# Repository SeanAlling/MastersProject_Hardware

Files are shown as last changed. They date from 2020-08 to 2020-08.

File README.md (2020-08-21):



# Overview 

Contains within this repository are the hardware files used for my masters project. One will find two sub directories

1. PrimaryPCB
1. TestBed

## Primary  PCB

This folder contains main PCB developed for the masters project. 

## Testbed 

This folder contain a PCB that can be used to simplify running experiments with the primary PCB.

# Special Thanks

<table><tr>
<td>  </td>
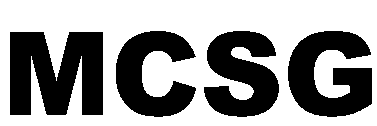
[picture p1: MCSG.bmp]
<td>  </td>
</tr></table>

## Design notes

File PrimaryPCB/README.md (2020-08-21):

# Overview

The project enclosed is the final version designed, developed, assembled, and tested for my Masters project at UC Davis. 

# Dependencies

This project was developed using EagleCAD 9.4.2. Different versions of eagle are not guaranteed to work.

__NOTE__: Libraries are not provided. Only the schematic and PCB project files are included.

# Project Structure

## BOM (Bill Of Material)

The BOM folder contains two different BOMs. First is a standard bill of material and contains an itemized list of the parts used in the project. 

A second BOM call iBOM (interactive BOM) is included that can be used to help find part placement during assembly.

## Documentation

Documentation folder contains a single PDF. The PDF contains all schematics, along with renderings of the top and bottom of the PCB, and images of each layer. 

## Gerbers

Contains a zip file that can be used for ordering the PCB from a manufacturer.

## Images

Raw images that are used in Documentation PDF.

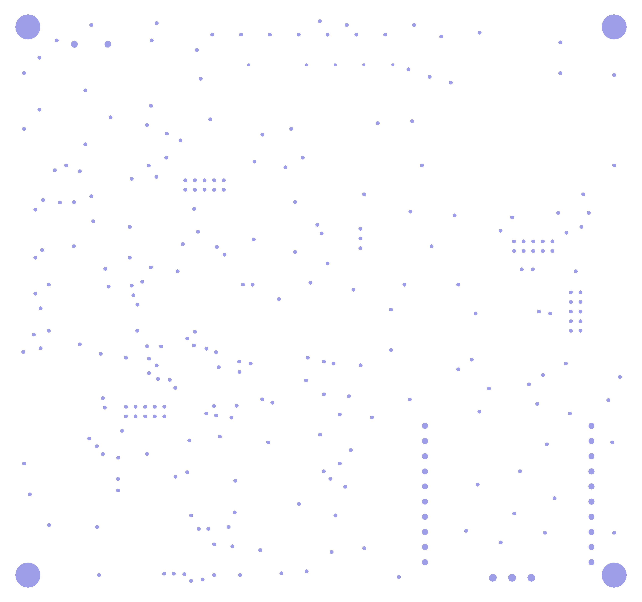
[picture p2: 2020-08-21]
PrimaryPCB/Images/output.png

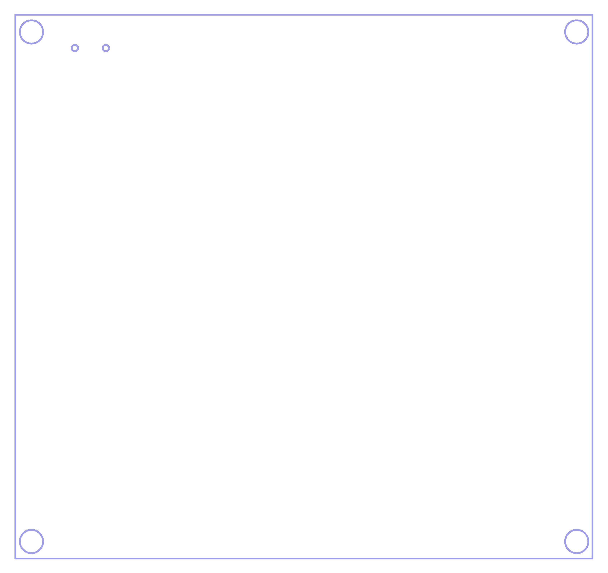
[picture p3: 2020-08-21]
PrimaryPCB/Images/bottompaste.png

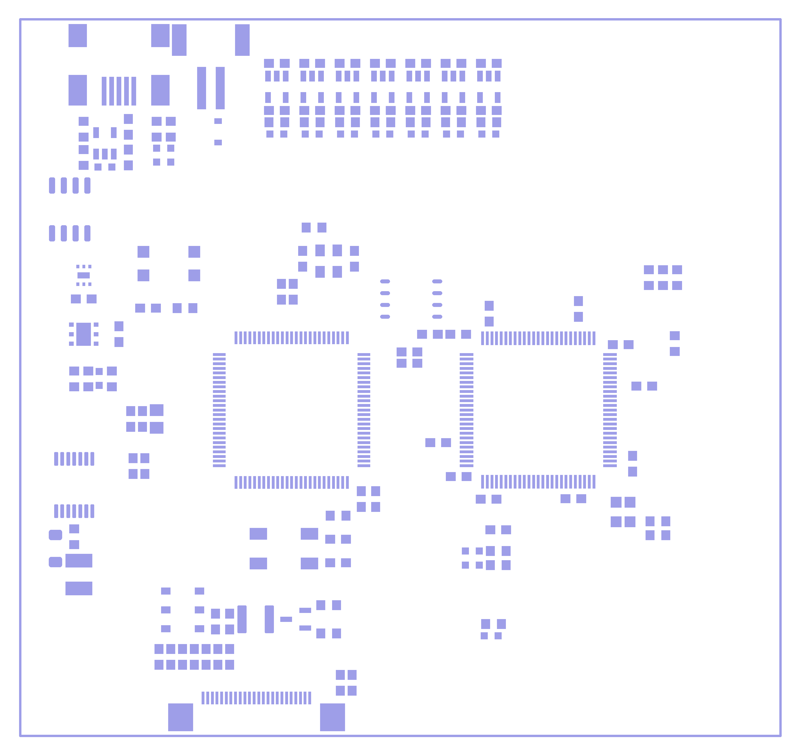
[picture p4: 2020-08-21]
PrimaryPCB/Images/topstencil.png

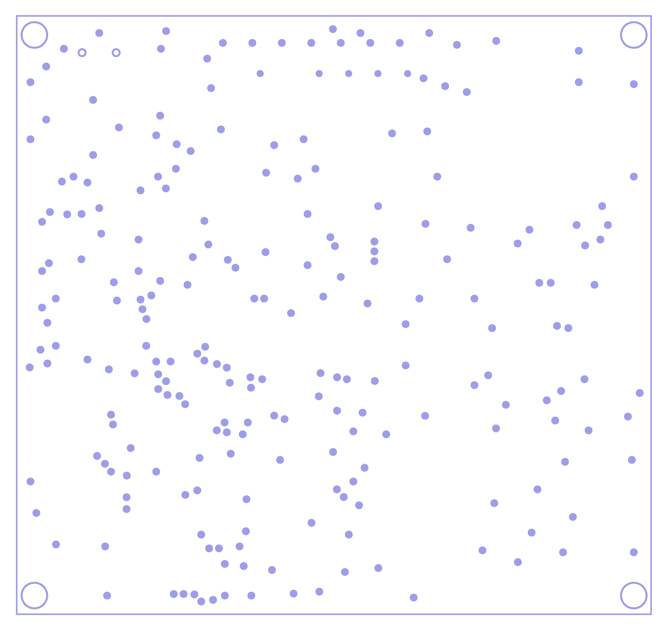
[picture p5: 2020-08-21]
PrimaryPCB/Images/drills.png

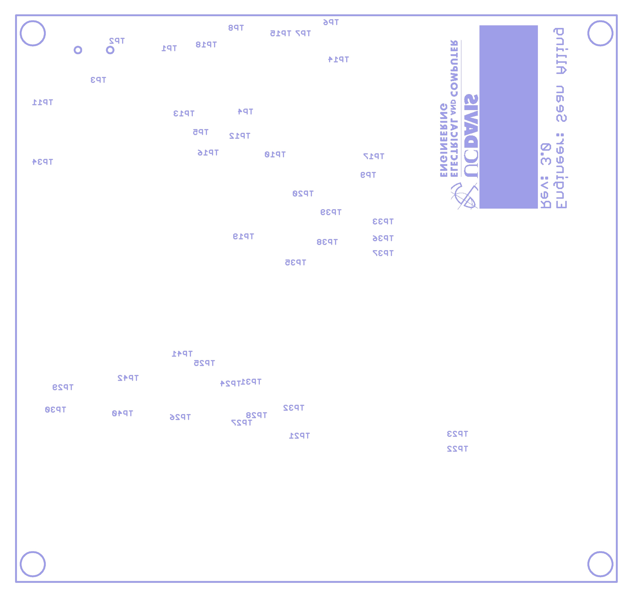
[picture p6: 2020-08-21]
PrimaryPCB/Images/bottomsilkscreen.png

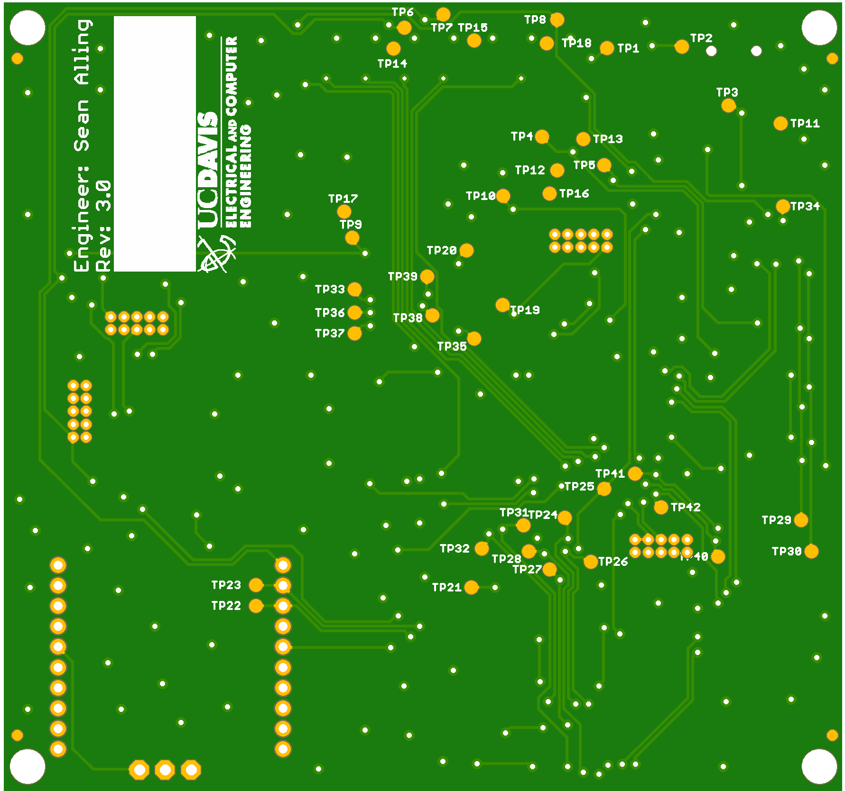
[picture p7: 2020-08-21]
PrimaryPCB/Images/PCB_Bottom.png

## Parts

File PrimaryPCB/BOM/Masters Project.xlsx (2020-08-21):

Qty | "Value" | "Package" | DIGIKEY
26 | "1uF" | "C0603" | 1276-1860-1-ND
6 | "4.7uF" | "C0603" | 1276-1907-1-ND
11 | "0.1uF" | "C0603" | 399-1100-1-ND
6 | "100nF" | "C0603" | 399-1100-1-ND
1 | "1nF" | "C0603" | 399-7833-1-ND
4 | "22pF" | "C0603" | 399-7874-1-ND
1 | "4uF" | "C0603" | 1276-1907-1-ND
1 | "47uF" | "C0603" | 490-13247-1-ND
1 | "11mF" | "C1210K" | 728-1127-1-ND
3 | "SCHOTTKY" | "SOD3716X128" | MBR0530T1GOSCT-ND
1 | "250mA/100V" | "SOD-323" | 1727-6169-1-ND
13 | "GREEN" | "CHIPLED_0603" | 732-4971-1-ND
1 | "RED" | "CHIPLED_0603" | 732-4978-1-ND
2 | "GREEN" | "SML0805" | 732-4983-1-ND
4 | "STAND-OFF" | "STAND-OFF"
1 | " " | "JST-2-SMD"
4 | "2X5_HEADER1.27MM" | "CORTEX_DEBUG_10PIN" | 3220-10-0100-00
1 | "1X3_HEADER" | "1X3_FEMALE_HEADER_THROUGH_HOLE" | S1012EC-40-ND
2 | " " | "XBEE-1" | ED11245-ND
1 | "4.7uH" | "L-USL0805" | LQM21PN4R7NGRD
1 | "100uH" | "LPS3015" | LPS3015-104MRC
1 | "CPFBZ-A2C4-32.768KD6" | "CPFBZ-A2C4-32.768KD6" | CPFBZ-A2C4-32.768KD6
1 | "ABM8-48.000MHZ-B2-T" | "CRYSTAL_4-SMD" | ABM8-48.000MHZ-B2-T
1 | "MOSFET-NCH" | "SOT95P237X112-3" | IRLML6346TRPBF
1 | "ABS07-LR" | "2-SMD" | ABS07-LR-32.768KHZ-6-T
1 | "0.47" | "R0603" | UCR03EVPFLR470
1 | "100k" | "R0603" | CR0603-JW-104ELF
9 | "1k" | "R0603" | 311-1.0KGRCT-ND
10 | "330" | "R0603" | CR0603-JW-331ELF
2 | "2k" | "R0603" | RC0603FR-072KL
2 | "10k" | "R0603" | RC0603JR-0710KL
1 | "91k" | "R0603" | RC0603FR-0791KL
3 | "51k" | "R0603" | RMCF0603JT5K10
1 | "TACTILE-SWITCH-SMT" | "7914G" | 7914G-1-000E
1 | "LCMXO2-640HC-4TG100C-NEW" | "QFP50P1600X1600X160-100N" | LCMXO2-640HC-4TG100C
1 | "MCP73831" | "SOT23-5L" | MCP73831T-2DCI/OT
6 | "STLQ015M33R" | "SOT23-5L" | STLQ015M33R
1 | "STLQ015M12R" | "SOT23-5L" | STLQ015M12R
1 | "HDC1080" | "WSON-6" | HDC1080DMBR
1 | "OPT3001" | "USON-6" | OPT3001DNPR
1 | "MSP432P401R" | "LQFP100" | MSP432P401RIPZR
1 | "AT25SL128A" | "SON127P600X500X60-8N" | AT25SL128A-MHE-T
1 | "PCF8523" | "TSSOP14" | PCF8523TS/1,118
1 | "FM24CL16B" | "FM24CL16B" | FM24CL16B-G
1 | "4.2-E-INK-DISPLAY" | "FPC-24PIN-0.5MM" | 524352471
1 | "MINI-USB-32005-201" | "32005-201" | UJ2-MABH-1-SMT-TR

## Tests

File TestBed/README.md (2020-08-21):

# Overview

The testbed project was designed to make reading test points simpler. Pogo pins are laid  out such that they align with a test pad on the primary PCB. The testbed also uses right angle header pins located to the sides of the PCB to allow probing signals. 

# Test Points

| TestPoint | Description |
| --- |:---:|
| 1 | +BAT|
| 2 | GND|
| 3 | VCC_USB|
| 4 | VCC_HDC1080|
| 5 | VCC_OPT3001|
| 6 | VCC_FPGA|
| 7 | VCC_XBEE|
| 8 | VCC_MEMORY|
| 9 | VCC_DISPLAY|
| 10 | VCC_MCU|
| 11 | GND|
| 12 | GND|
| 13 | GND|
| 14 | GND|
| 15 | GND|
| 16 | GND|
| 17 | GND|
| 18 | GND|
| 19 | <span style="text-decoration:overline">RST</span>|
| 20 | N$139|
| 21 | N$131|
| 22 | UART_TX_XBEE|
| 23 | UART_RX_XBEE|
| 24 | SPI_CLK|
| 25 | CHARGE_STATUS|
| 26 | SPI_MOSI|
| 27 | DISPLAY_D/<span style="text-decoration:overline">C</span>|
| 28 | SPI_CS_DISPLAY|
| 29 | MCU_SCL|
| 30 | MCU_SDA|
| 31 | EINK_<span style="text-decoration:overline">RST</span>|
| 32 | EINK_BUSY|
| 33 | <span style="text-decoration:overline">FLASH_WP</span>|
| 34 | FRAM_WP|
| 35 | <span style="text-decoration:overline">FLASH_HOLD</span>|
| 36 | MCU_SPI_MISO|
| 37 | MCU_SPI_CS|
| 38 | MCU_SPI_CLK|
| 39 | SPI_MOSI|
| 40 | <span style="text-decoration:overline">RTC_IN1</span>|
| 41 | RTC_CLKOUT|
| 42 | <span style="text-decoration:overline">RTC_INT2</span>|

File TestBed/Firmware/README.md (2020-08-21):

# Dependencies
This project was created using STM32CubeMX Version 5.2.0. Only Version 5.2.0 of STM32CubeMX is guaranteed to work.

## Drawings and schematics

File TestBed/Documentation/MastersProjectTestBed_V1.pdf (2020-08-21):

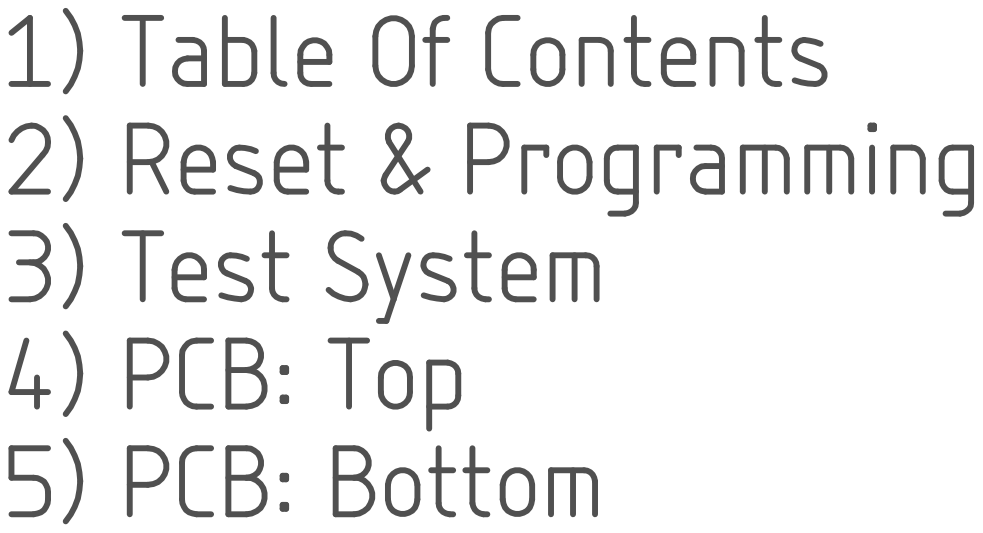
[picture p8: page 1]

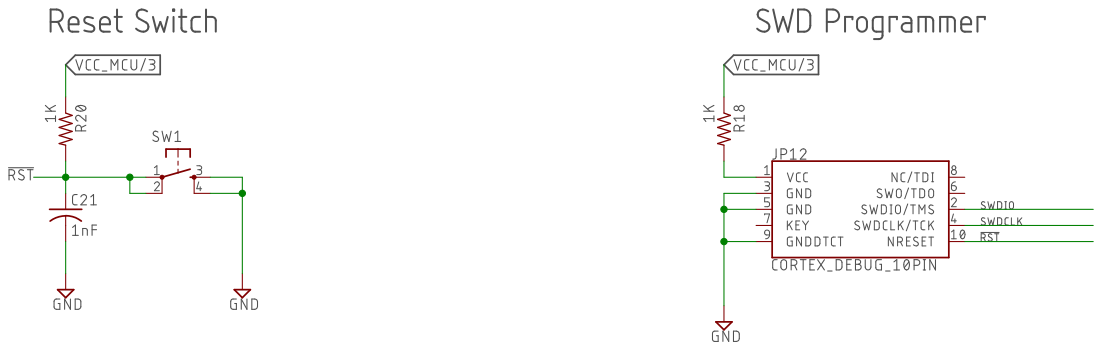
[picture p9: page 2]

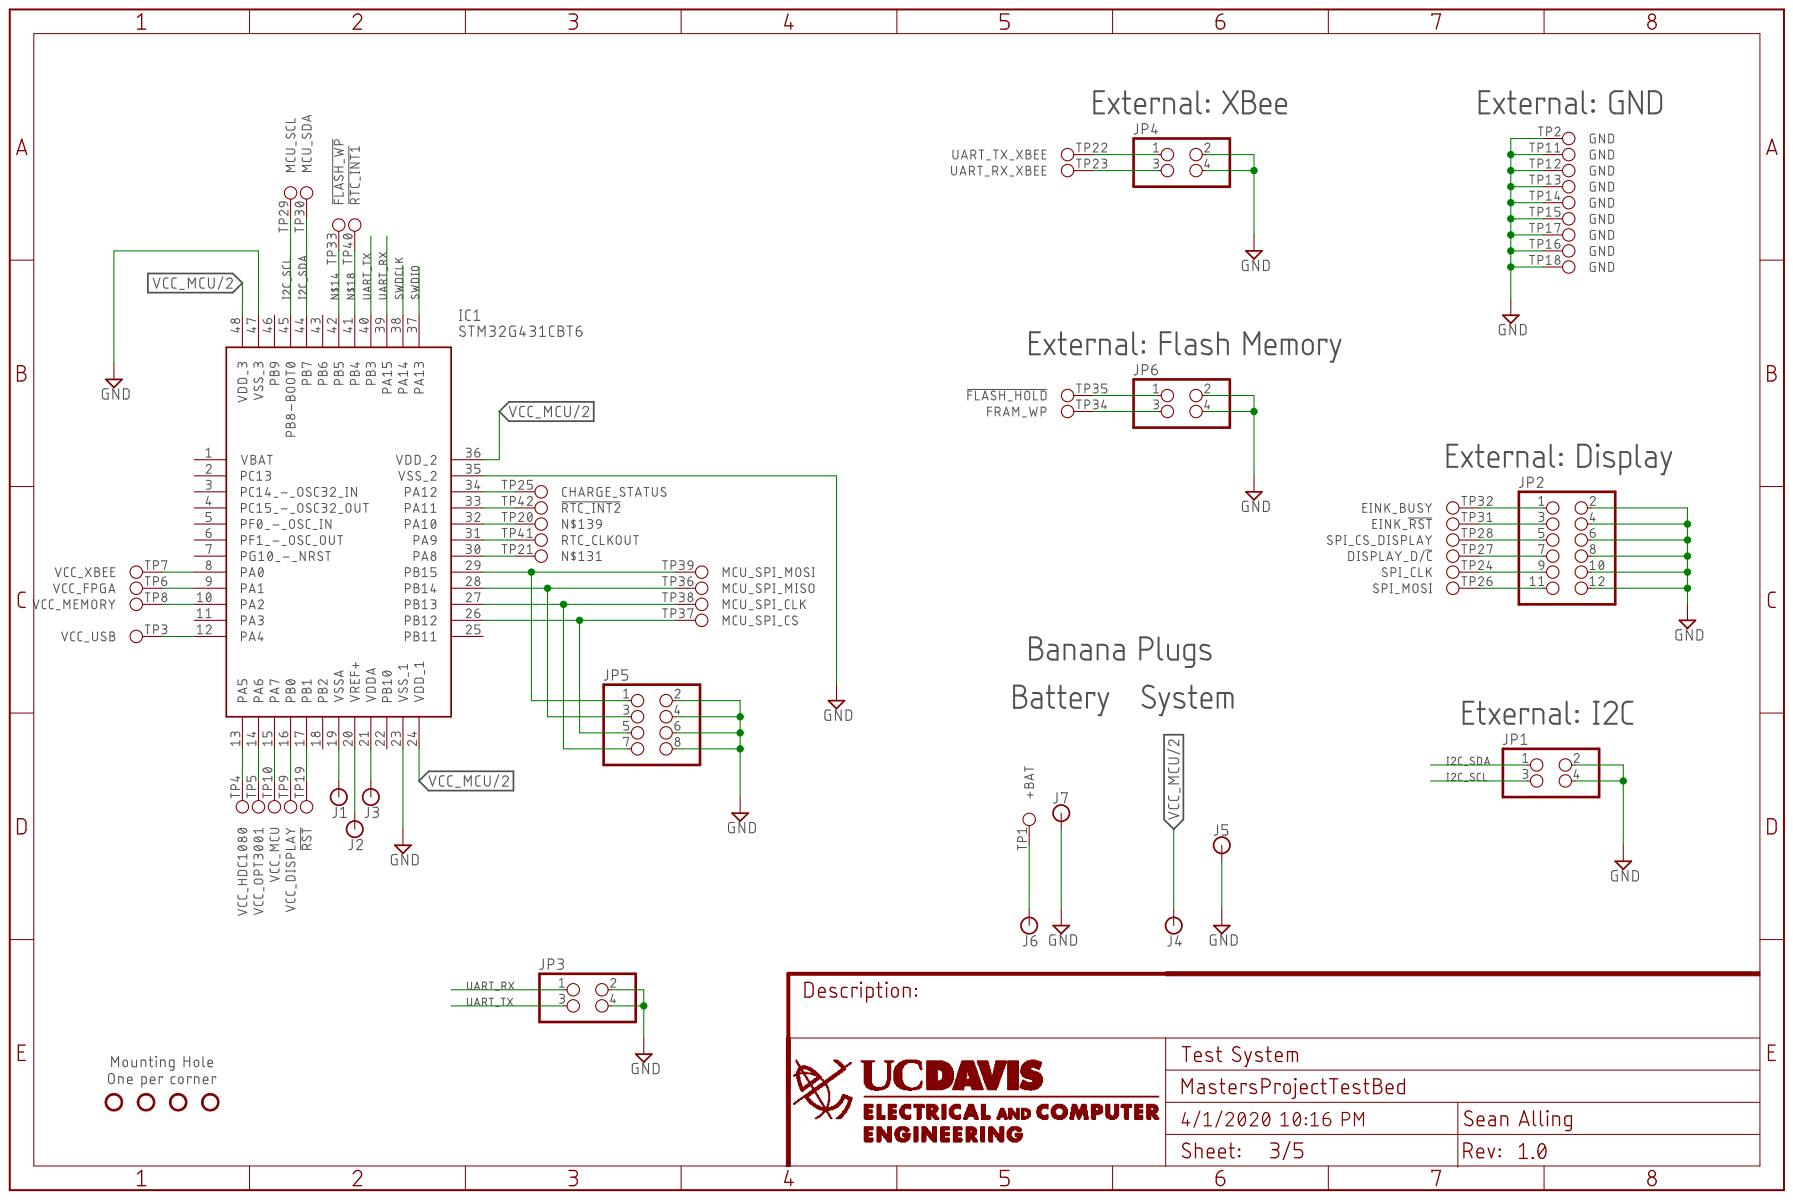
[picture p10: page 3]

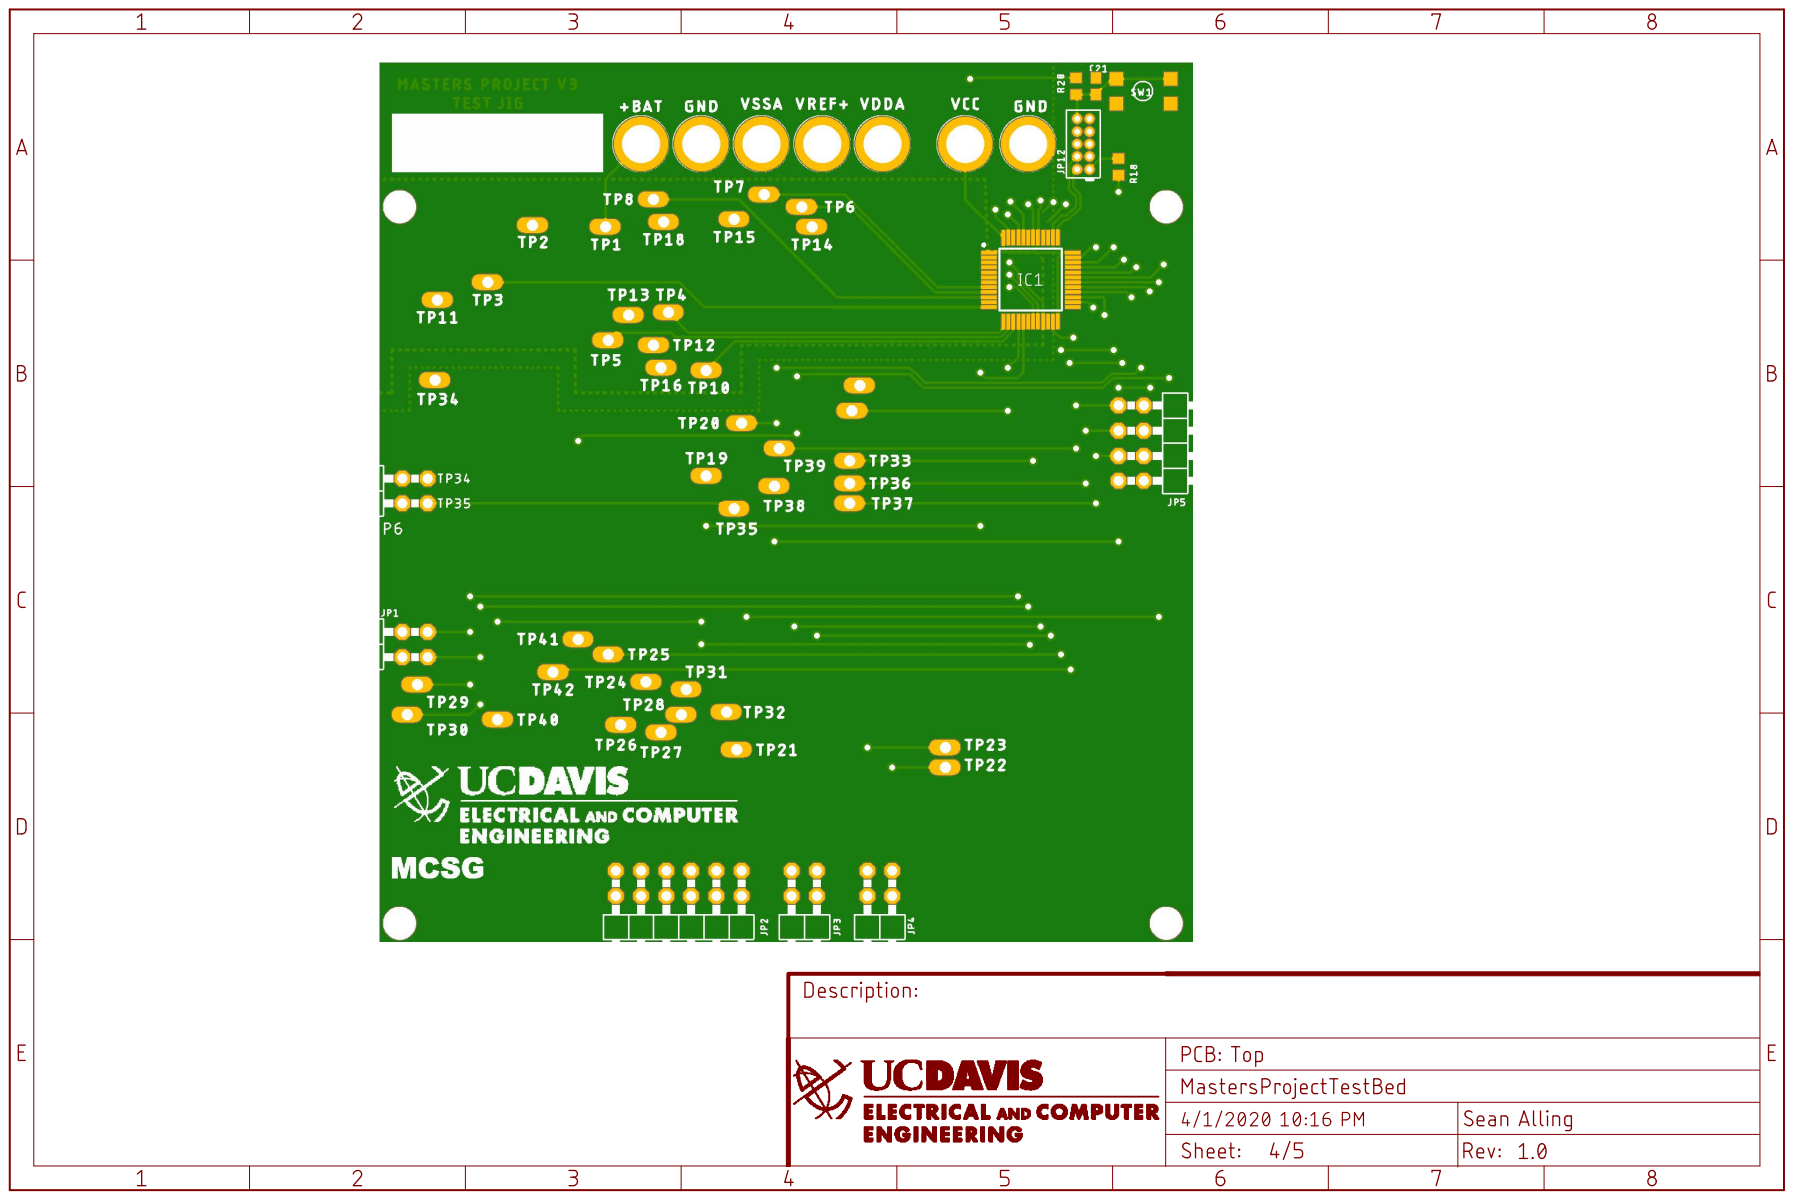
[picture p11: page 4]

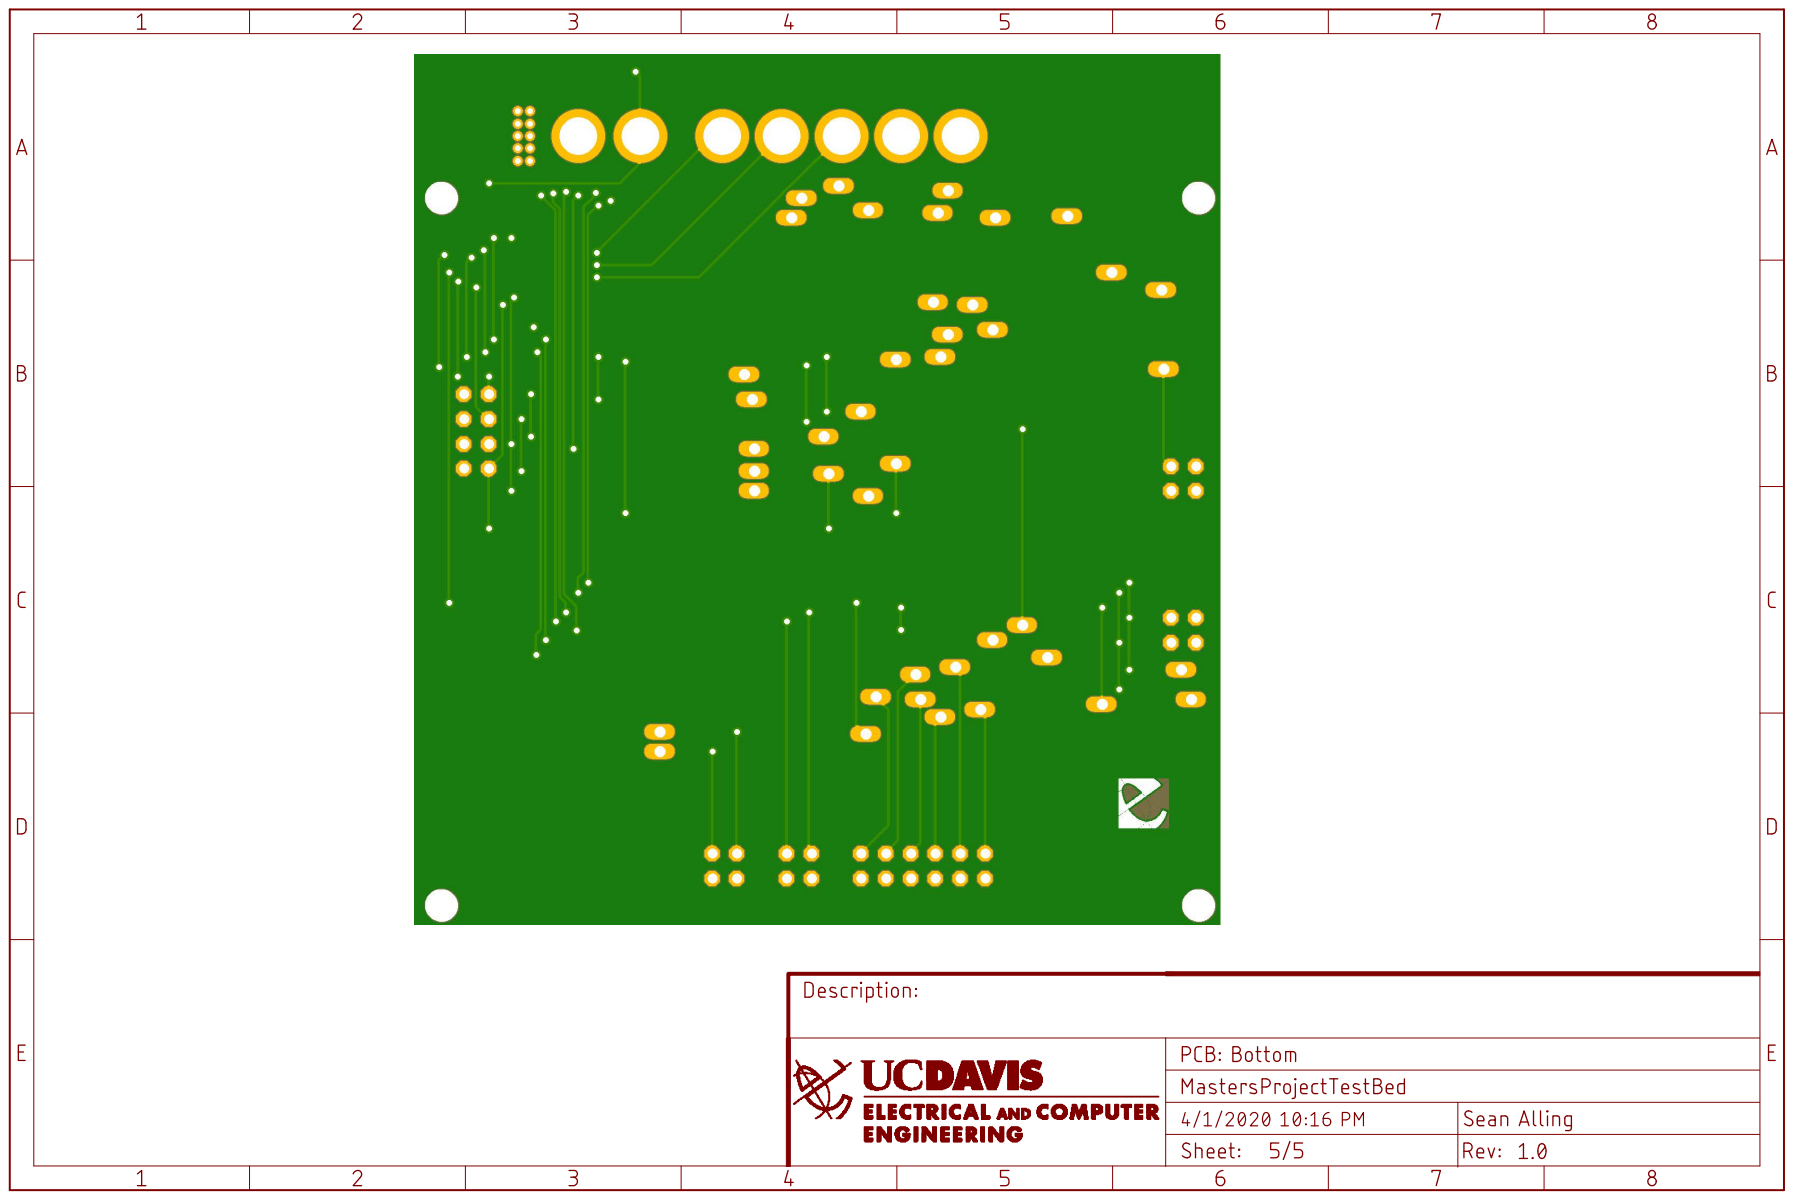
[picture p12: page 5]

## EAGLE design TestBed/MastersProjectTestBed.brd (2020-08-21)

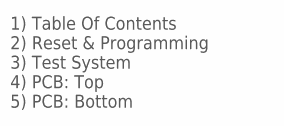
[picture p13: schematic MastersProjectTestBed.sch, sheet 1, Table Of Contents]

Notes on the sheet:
1) Table Of Contents 2) Reset & Programming 3) Test System 4) PCB: Top 5) PCB: Bottom

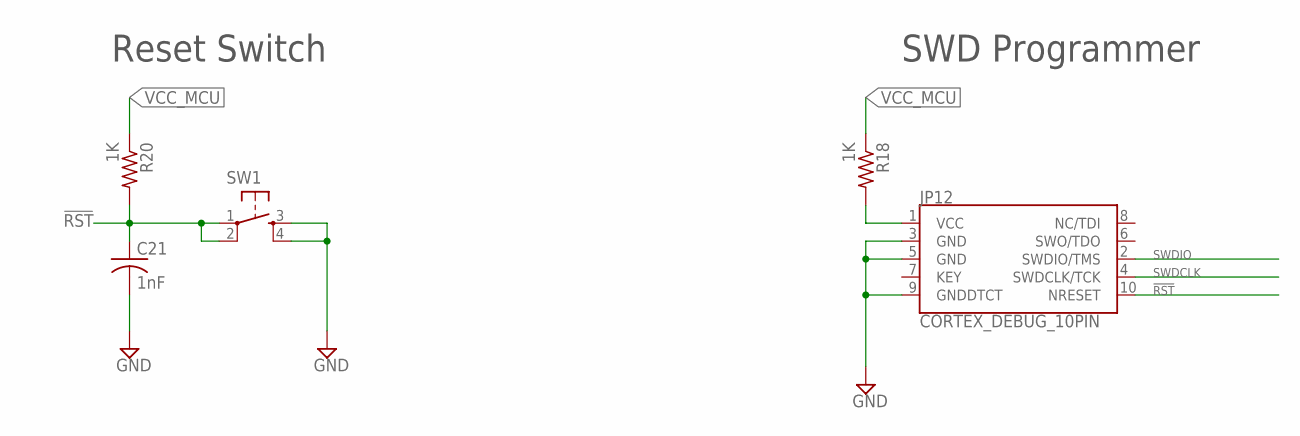
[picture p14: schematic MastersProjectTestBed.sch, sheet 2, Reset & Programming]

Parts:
C21: 1nF; C0603; PARTNO 08053F102K4T2A
JP12: CORTEX_DEBUG_10PIN; PARTNO 3220-10-0100-00
R18, R20: 1K; R0603; PARTNO RC0805JR-071KL
SW1: TACTILE-SWITCH-SMT; 7914G; PARTNO 7914G-1-000E

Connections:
!RST: C21.1, JP12.10 (NRESET), R20.2, SW1.1, SW1.2
GND: C21.2, JP12.3 (GND), JP12.5 (GND), JP12.9 (GNDDTCT), SW1.3, SW1.4; also elsewhere on the board
unnamed: JP12.1 (VCC), R18.2
SWDCLK: JP12.4 (SWDCLK/TCK); also elsewhere on the board
SWDIO: JP12.2 (SWDIO/TMS); also elsewhere on the board
VCC_MCU: R18.1, R20.1; also elsewhere on the board

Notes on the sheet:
SWD Programmer
Reset Switch

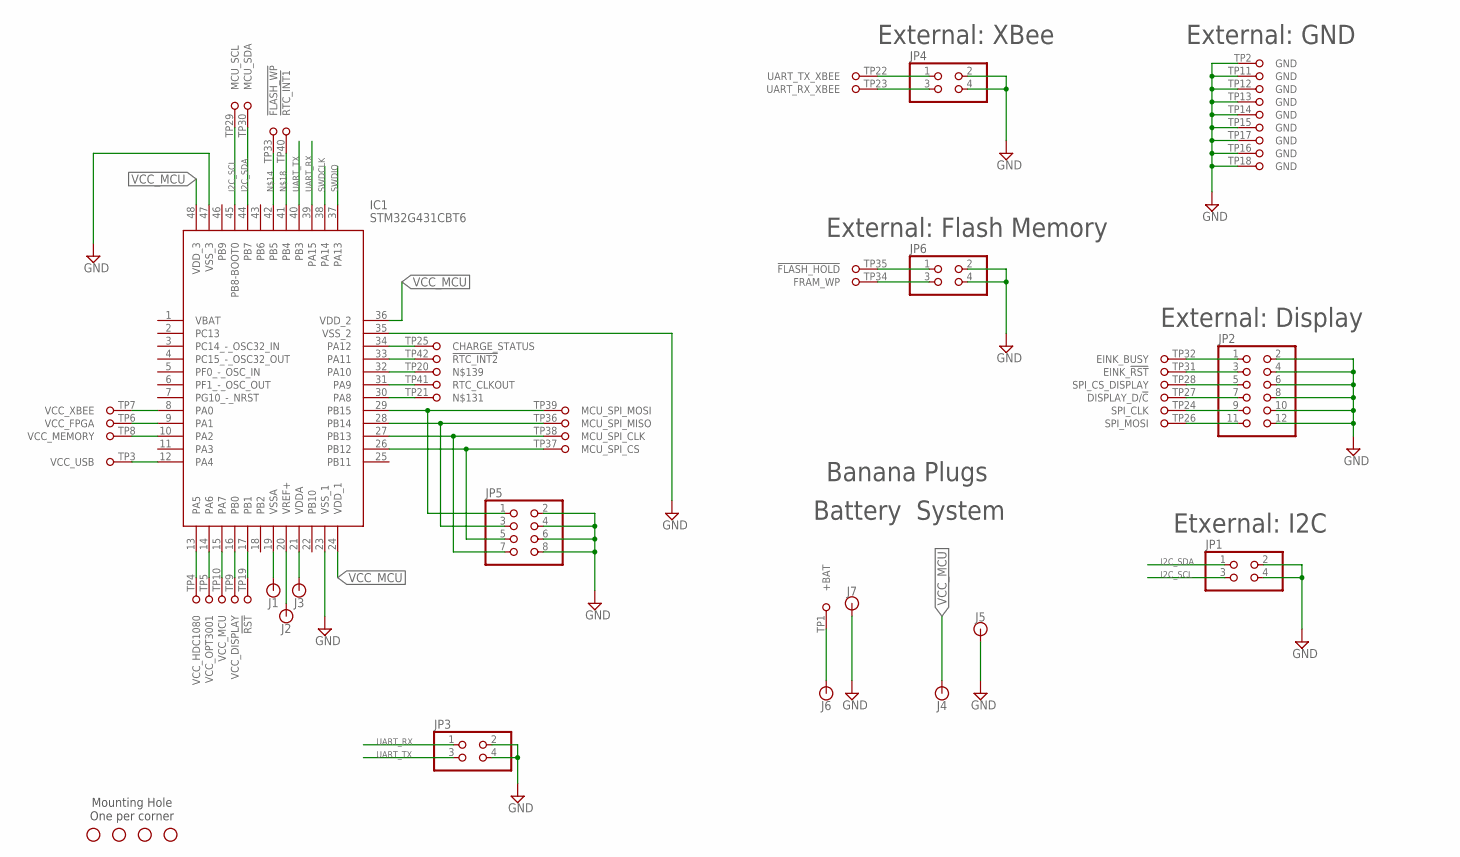
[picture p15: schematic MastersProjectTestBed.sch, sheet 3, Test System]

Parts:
H1, H2, H3, H4: STAND-OFF
IC1: STM32G431CBT6; QFP50P900X900X160-48N
J1, J2, J3, J4, J5, J6, J7: BANANA_CONN
JP1, JP3, JP4, JP6: PINHD-2X2/90; 2X02/90
JP2: PINHD-2X6/90; 2X06/90
JP5: PINHD-2X4/90; 2X04/90
TP1: PCB-POGO

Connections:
GND: IC1.23 (VSS_1), IC1.35 (VSS_2), IC1.47 (VSS_3), J5.P$1, J7.P$1, JP1.2, JP1.4, JP2.2, JP2.4, JP2.6, JP2.8, JP2.10, JP2.12, JP3.2, JP3.4, JP4.2, JP4.4, JP5.2, JP5.4, JP5.6, JP5.8, JP6.2, JP6.4, TP1.TP2 (GND), TP1.TP11 (GND), TP1.TP12 (GND), TP1.TP13 (GND), TP1.TP14 (GND), TP1.TP15 (GND), TP1.TP16 (GND), TP1.TP17 (GND), TP1.TP18 (GND); also elsewhere on the board
I2C_SCL: IC1.45 (PB8-BOOT0), JP1.3, TP1.TP29 (MCU_SCL)
I2C_SDA: IC1.44 (PB7), JP1.1, TP1.TP30 (MCU_SDA)
unnamed: IC1.9 (PA1), TP1.TP6 (VCC_FPGA)
unnamed: IC1.8 (PA0), TP1.TP7 (VCC_XBEE)
unnamed: IC1.10 (PA2), TP1.TP8 (VCC_MEMORY)
unnamed: J6.P$1, TP1.TP1 (+BAT)
unnamed: IC1.12 (PA4), TP1.TP3 (VCC_USB)
unnamed: IC1.33 (PA11), TP1.TP42 (!RTC_INT2)
unnamed: IC1.34 (PA12), TP1.TP25 (CHARGE_STATUS)
unnamed: IC1.13 (PA5), TP1.TP4 (VCC_HDC1080)
unnamed: IC1.14 (PA6), TP1.TP5 (VCC_OPT3001)
unnamed: IC1.15 (PA7), TP1.TP10 (VCC_MCU)
unnamed: IC1.17 (PB1), TP1.TP19 (!RST)
unnamed: IC1.30 (PA8), TP1.TP21
unnamed: IC1.42 (PB5), TP1.TP33 (!FLASH_WP)
unnamed: JP6.1, TP1.TP35 (!FLASH_HOLD)
unnamed: JP6.3, TP1.TP34 (FRAM_WP)
unnamed: IC1.16 (PB0), TP1.TP9 (VCC_DISPLAY)
unnamed: IC1.41 (PB4), TP1.TP40 (!RTC_INT1)
unnamed: IC1.32 (PA10), TP1.TP20
unnamed: IC1.31 (PA9), TP1.TP41 (RTC_CLKOUT)
unnamed: JP2.9, TP1.TP24 (SPI_CLK)
unnamed: JP2.11, TP1.TP26 (SPI_MOSI)
unnamed: JP2.7, TP1.TP27 (DISPLAY_D/!C)
unnamed: JP2.5, TP1.TP28 (SPI_CS_DISPLAY)
unnamed: JP2.3, TP1.TP31 (EINK_!RST)
unnamed: JP2.1, TP1.TP32 (EINK_BUSY)
unnamed: JP4.1, TP1.TP22 (UART_TX_XBEE)
unnamed: JP4.3, TP1.TP23 (UART_RX_XBEE)
unnamed: IC1.29 (PB15), JP5.1, TP1.TP39 (MCU_SPI_MOSI)
unnamed: IC1.28 (PB14), JP5.3, TP1.TP36 (MCU_SPI_MISO)
unnamed: IC1.27 (PB13), JP5.7, TP1.TP38 (MCU_SPI_CLK)
unnamed: IC1.26 (PB12), JP5.5, TP1.TP37 (MCU_SPI_CS)
unnamed: IC1.19 (VSSA), J1.P$1
unnamed: IC1.20 (VREF+), J2.P$1
unnamed: IC1.21 (VDDA), J3.P$1
SWDCLK: IC1.38 (PA14); also elsewhere on the board
SWDIO: IC1.37 (PA13); also elsewhere on the board
UART_RX: IC1.39 (PA15), JP3.1
UART_TX: IC1.40 (PB3), JP3.3
VCC_MCU: IC1.24 (VDD_1), IC1.36 (VDD_2), IC1.48 (VDD_3), J4.P$1; also elsewhere on the board

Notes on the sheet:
Mounting Hole One per corner
External: GND
External: Display
Etxernal: I2C
External: XBee
External: Flash Memory
Banana Plugs
Battery
System

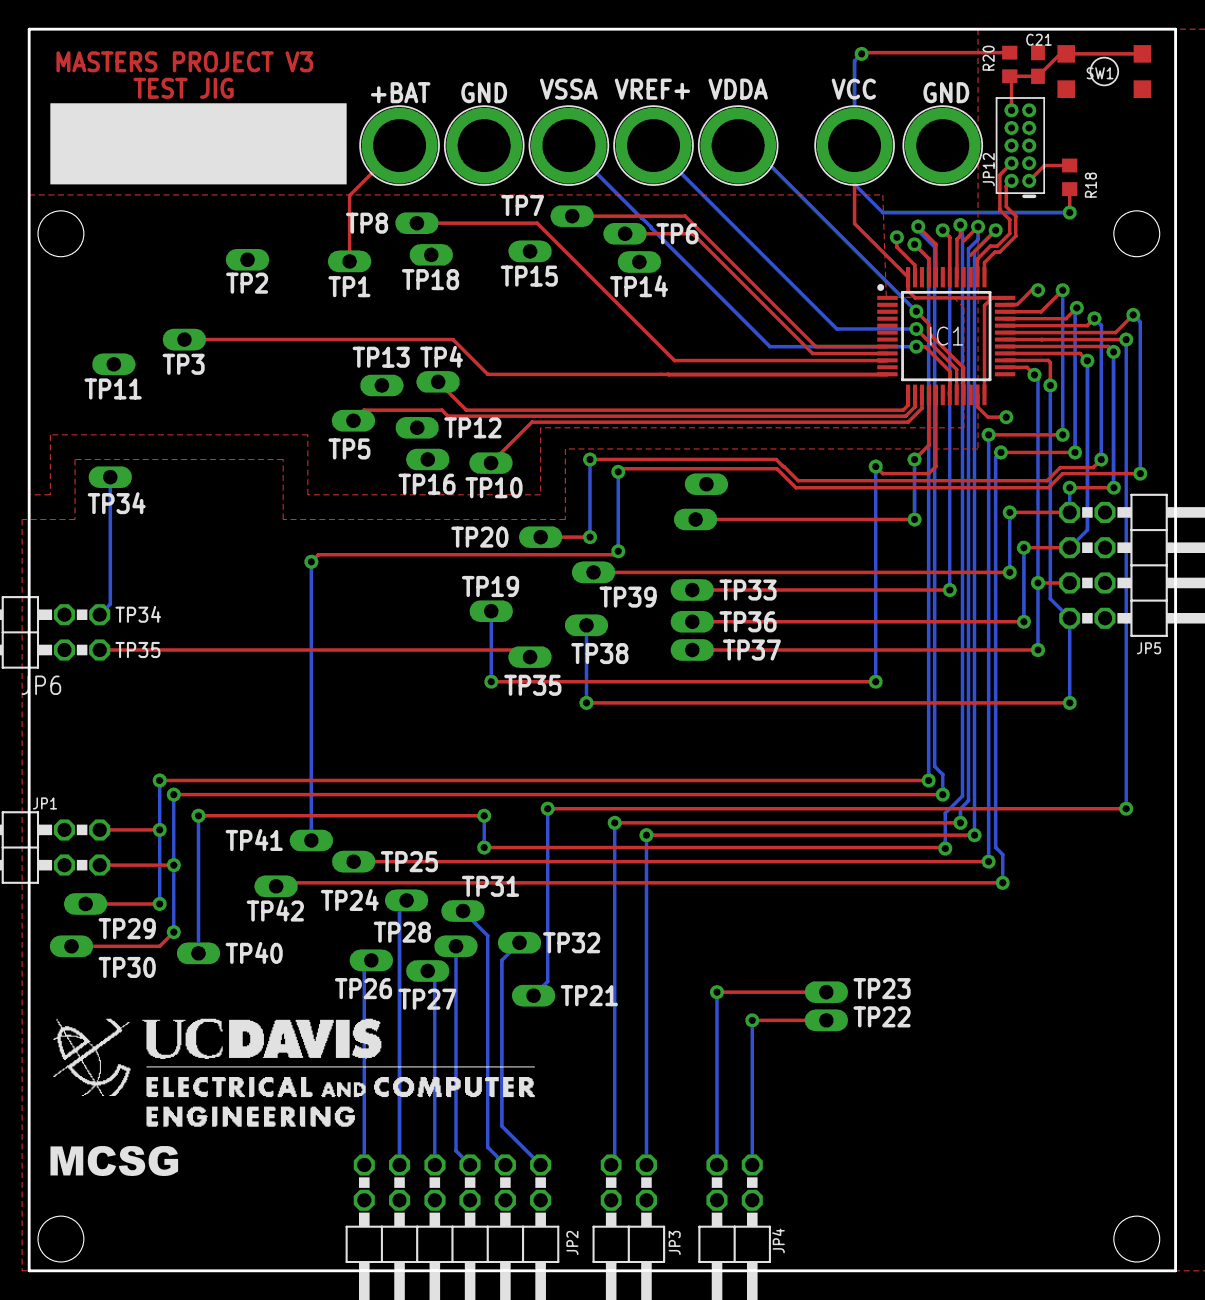
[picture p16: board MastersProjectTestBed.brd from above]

Board: 2 copper layers, 82.5 x 89.4 mm, 27 parts (1 on the bottom side), 44 nets.

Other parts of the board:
U$1: UC_DAVIS_ENG
U$2: MCSG_SMALL
U$3: UC_DAVIS_EEC

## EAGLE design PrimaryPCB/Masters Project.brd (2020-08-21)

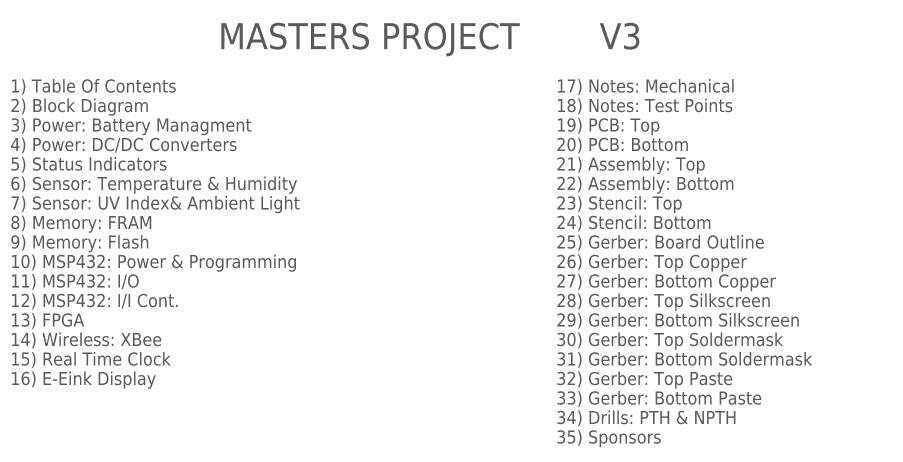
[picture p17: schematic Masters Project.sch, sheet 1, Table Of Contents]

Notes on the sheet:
MASTERS PROJECT
1) Table Of Contents 2) Block Diagram 3) Power: Battery Managment 4) Power: DC/DC Converters 5) Status Indicators 6) Sensor: Temperature & Humidity 7) Sensor: UV Index& Ambient Light 8) Memory: FRAM 9) Memory: Flash 10) MSP432: Power & Programming 11) MSP432: I/O 12) MSP432: I/I Cont. 13) FPGA 14) 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
17) Notes: Mechanical 18) Notes: Test Points 19) PCB: Top 20) PCB: Bottom 21) Assembly: Top 22) Assembly: Bottom 23) Stencil: Top 24) Stencil: Bottom 25) Gerber: Board Outline 26) Gerber: Top Copper 27) Gerber: Bottom Copper 28) Gerber: Top Silkscreen 29) Gerber: Bottom Silkscreen 30) Gerber: Top S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

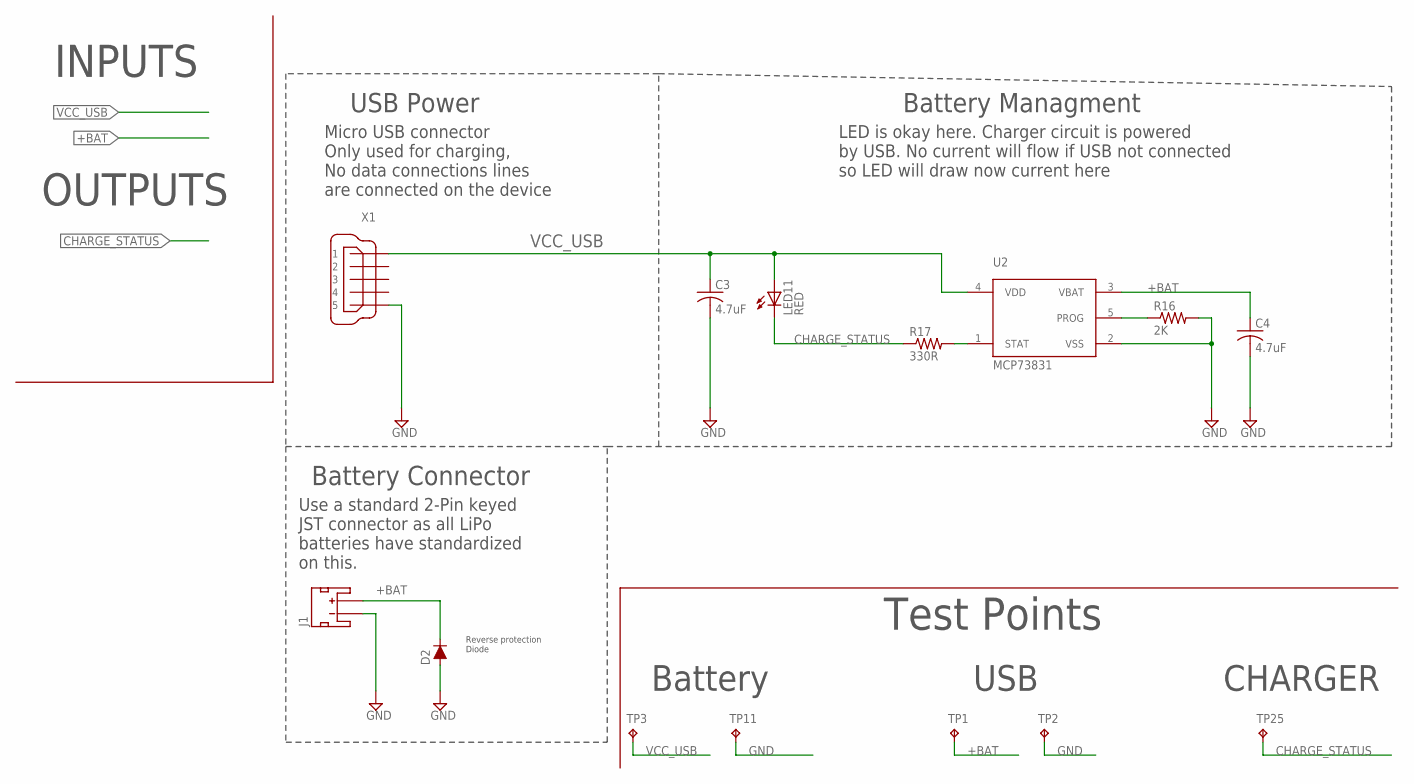
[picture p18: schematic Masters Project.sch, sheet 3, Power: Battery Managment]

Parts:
C3, C4: 4.7uF; C0603; PARTNO CL21A475KBQNNNE
D2: 250mA/100V; SOD-323
J1: JST_2MM_MALE; JST-2-SMD; PARTNO S2B-PH-SM4-TB(LF)(SN)
LED11: RED; CHIPLED_0603; PARTNO LG R971-KN-1
R16: 2K; R0603; PARTNO RC0805FR-072KL
R17: 330R; R0603; PARTNO RMCF0805JT330R
TP1, TP2, TP3, TP11, TP25: TPB1,27; B1,27
U2: MCP73831; SOT23-5L; PARTNO MCP73831T-2ATI/OT
X1: MINI-USB-32005-201; 32005-201; PARTNO 10033526-N3212LF

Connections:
+BAT: C4.1, D2.C, J1.2 (+), TP1.TP, U2.3 (VBAT); also elsewhere on the board
CHARGE_STATUS: LED11.C, R17.1, TP25.TP; also elsewhere on the board
GND: C3.2, C4.2, D2.A, J1.1 (-), R16.2, TP2.TP, TP11.TP, U2.2 (VSS), X1.5; also elsewhere on the board
unnamed: R17.2, U2.1 (STAT)
unnamed: R16.1, U2.5 (PROG)
VCC_USB: C3.1, LED11.A, TP3.TP, U2.4 (VDD), X1.1; also elsewhere on the board

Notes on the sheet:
Battery Managment
Battery Connector
USB Power
Micro USB connector Only used for charging, No data connections lines are connected on the device
Reverse protection Diode
Use a standard 2-Pin keyed JST connector as all LiPo batteries have standardized on this.
Test Points
Battery
USB
CHARGER
LED is okay here. Charger circuit is powered by USB. No current will flow if USB not connected so LED will draw now current here
INPUTS
OUTPUTS

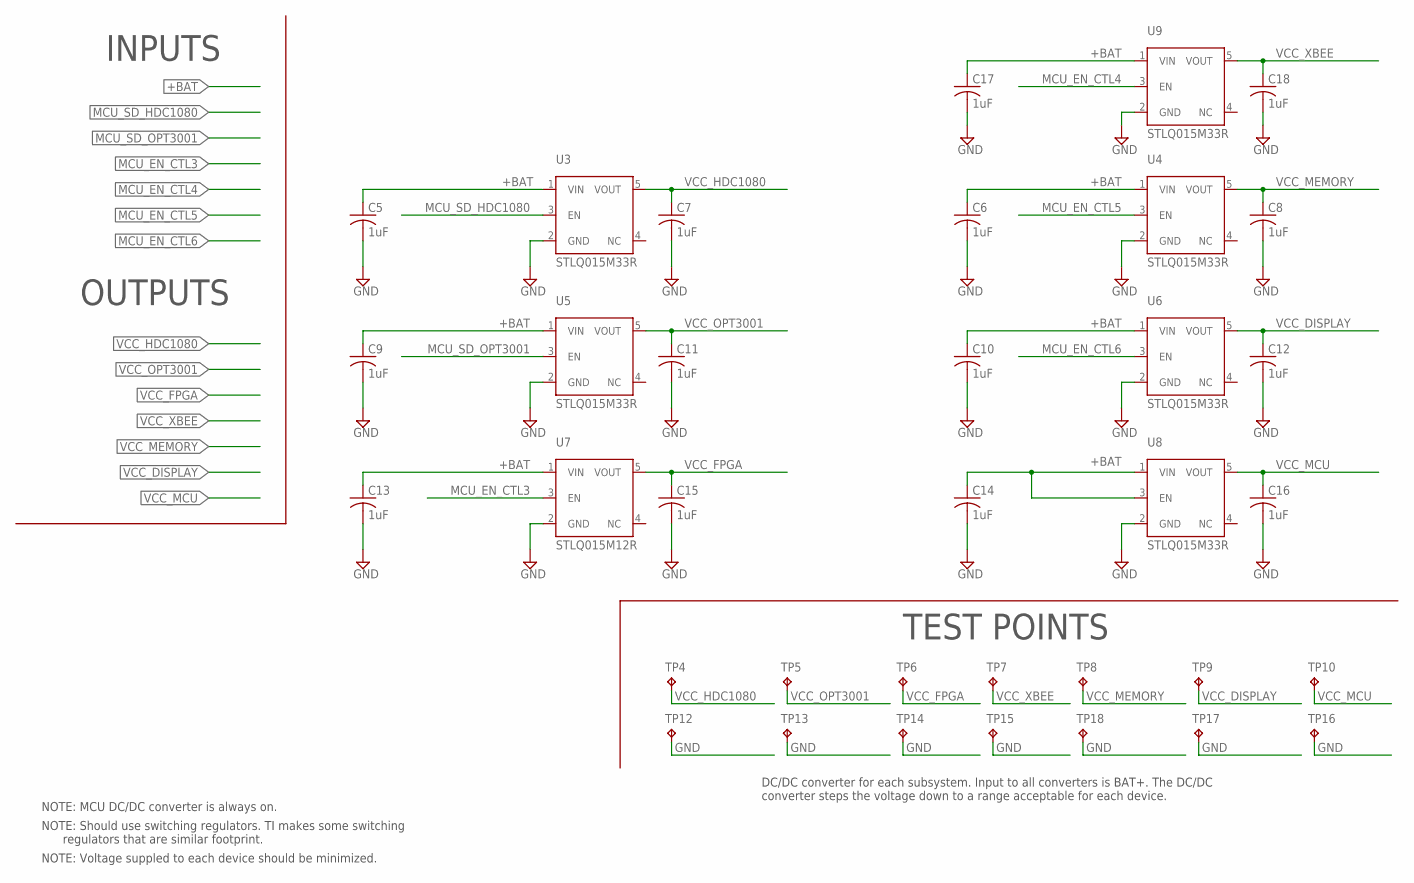
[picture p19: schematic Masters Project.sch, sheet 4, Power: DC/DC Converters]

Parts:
C5, C6, C7, C8, C9, C10, C11, C12, C13, C14, C15, C16, C17, C18: 1uF; C0603; PARTNO CC0805ZKY5V9BB105
TP4, TP5, TP6, TP7, TP8, TP9, TP10, TP12, TP13, TP14, TP15, TP16, TP17, TP18: TPB1,27; B1,27
U3, U5, U6, U8, U9: STLQ015M33R; SOT23-5L; PARTNO STLQ015M33R
U4: STLQ015M33R; SOT23-5L; PARTNO STLQ015M12R
U7: STLQ015M12R; SOT23-5L; PARTNO STLQ015M12R

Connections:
+BAT: C5.1, C6.1, C9.1, C10.1, C13.1, C14.1, C17.1, U3.1 (VIN), U4.1 (VIN), U5.1 (VIN), U6.1 (VIN), U7.1 (VIN), U8.1 (VIN), U8.3 (EN), U9.1 (VIN); also elsewhere on the board
GND: C5.2, C6.2, C7.2, C8.2, C9.2, C10.2, C11.2, C12.2, C13.2, C14.2, C15.2, C16.2, C17.2, C18.2, TP12.TP, TP13.TP, TP14.TP, TP15.TP, TP16.TP, TP17.TP, TP18.TP, U3.2 (GND), U4.2 (GND), U5.2 (GND), U6.2 (GND), U7.2 (GND), U8.2 (GND), U9.2 (GND); also elsewhere on the board
MCU_EN_CTL3: U7.3 (EN); also elsewhere on the board
MCU_EN_CTL4: U9.3 (EN); also elsewhere on the board
MCU_EN_CTL5: U4.3 (EN); also elsewhere on the board
MCU_EN_CTL6: U6.3 (EN); also elsewhere on the board
MCU_SD_HDC1080: U3.3 (EN); also elsewhere on the board
MCU_SD_OPT3001: U5.3 (EN); also elsewhere on the board
VCC_DISPLAY: C12.1, TP9.TP, U6.5 (VOUT); also elsewhere on the board
VCC_FPGA: C15.1, TP6.TP, U7.5 (VOUT); also elsewhere on the board
VCC_HDC1080: C7.1, TP4.TP, U3.5 (VOUT); also elsewhere on the board
VCC_MCU: C16.1, TP10.TP, U8.5 (VOUT); also elsewhere on the board
VCC_MEMORY: C8.1, TP8.TP, U4.5 (VOUT); also elsewhere on the board
VCC_OPT3001: C11.1, TP5.TP, U5.5 (VOUT); also elsewhere on the board
VCC_XBEE: C18.1, TP7.TP, U9.5 (VOUT); also elsewhere on the board

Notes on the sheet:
DC/DC converter for each subsystem. Input to all converters is BAT+. The DC/DC converter steps the voltage down to a range acceptable for each device.
TEST POINTS
INPUTS
OUTPUTS
NOTE: MCU DC/DC converter is always on.
NOTE: Should use switching regulators. TI makes some switching regulators that are similar footprint.
NOTE: Voltage suppled to each device should be minimized.

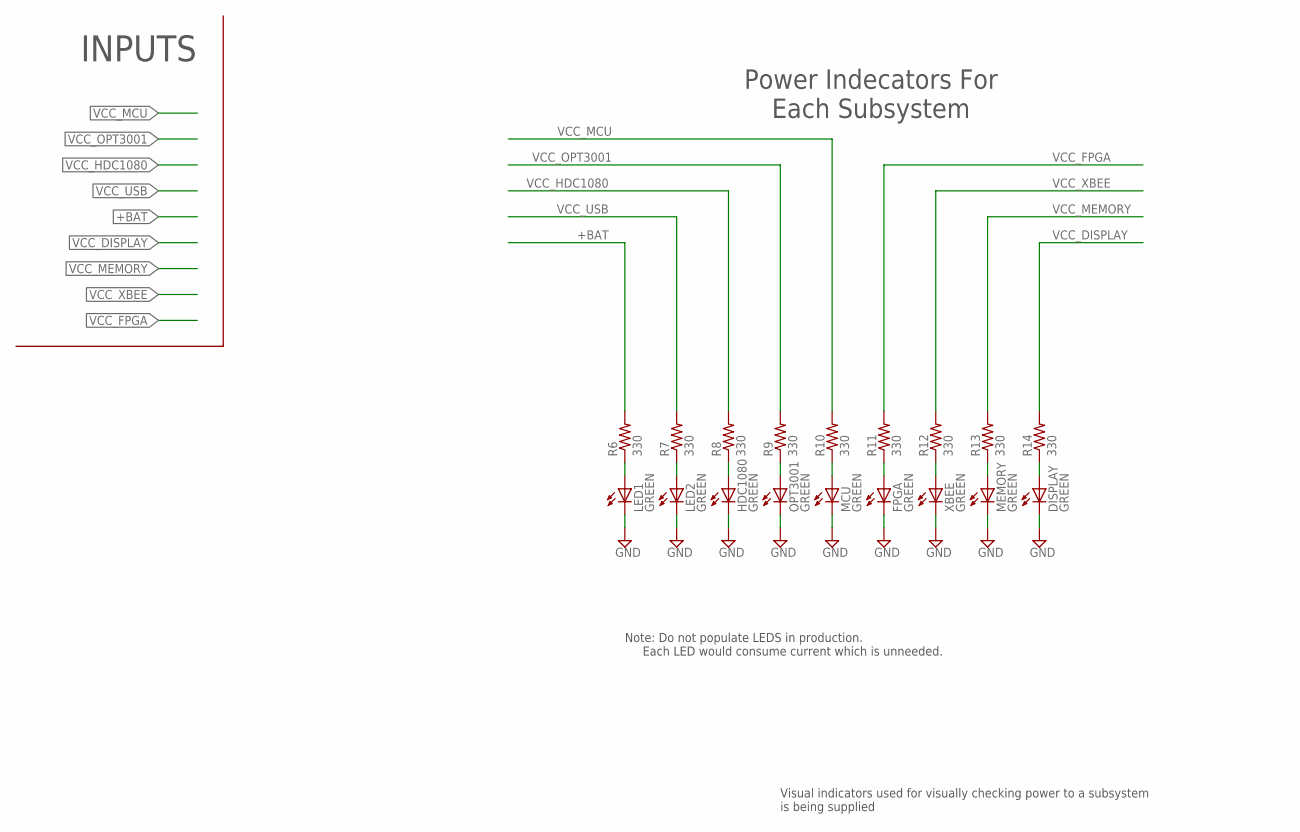
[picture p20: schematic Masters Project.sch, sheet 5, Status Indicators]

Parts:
DISPLAY: GREEN; CHIPLED_0603; PARTNO LG R971-KN-1
FPGA: GREEN; CHIPLED_0603; PARTNO LG R971-KN-1
HDC1080: GREEN; CHIPLED_0603; PARTNO LG R971-KN-1
LED1, LED2: GREEN; CHIPLED_0603; PARTNO LG R971-KN-1
MCU: GREEN; CHIPLED_0603; PARTNO LG R971-KN-1
MEMORY: GREEN; CHIPLED_0603; PARTNO LG R971-KN-1
OPT3001: GREEN; CHIPLED_0603; PARTNO LG R971-KN-1
R6, R7, R8, R9, R10, R11, R12, R13, R14: 330; R0603; PARTNO RMCF0805JT330R
XBEE: GREEN; CHIPLED_0603; PARTNO LG R971-KN-1

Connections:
+BAT: R6.2; also elsewhere on the board
GND: DISPLAY.C, FPGA.C, HDC1080.C, LED1.C, LED2.C, MCU.C, MEMORY.C, OPT3001.C, XBEE.C; also elsewhere on the board
unnamed: LED1.A, R6.1
unnamed: LED2.A, R7.1
unnamed: HDC1080.A, R8.1
unnamed: OPT3001.A, R9.1
unnamed: MCU.A, R10.1
unnamed: FPGA.A, R11.1
unnamed: DISPLAY.A, R14.1
unnamed: MEMORY.A, R13.1
unnamed: R12.1, XBEE.A
VCC_DISPLAY: R14.2; also elsewhere on the board
VCC_FPGA: R11.2; also elsewhere on the board
VCC_HDC1080: R8.2; also elsewhere on the board
VCC_MCU: R10.2; also elsewhere on the board
VCC_MEMORY: R13.2; also elsewhere on the board
VCC_OPT3001: R9.2; also elsewhere on the board
VCC_USB: R7.2; also elsewhere on the board
VCC_XBEE: R12.2; also elsewhere on the board

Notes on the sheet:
Power Indecators For Each Subsystem
INPUTS
Visual indicators used for visually checking power to a subsystem is being supplied
Note: Do not populate LEDS in production. Each LED would consume current which is unneeded.

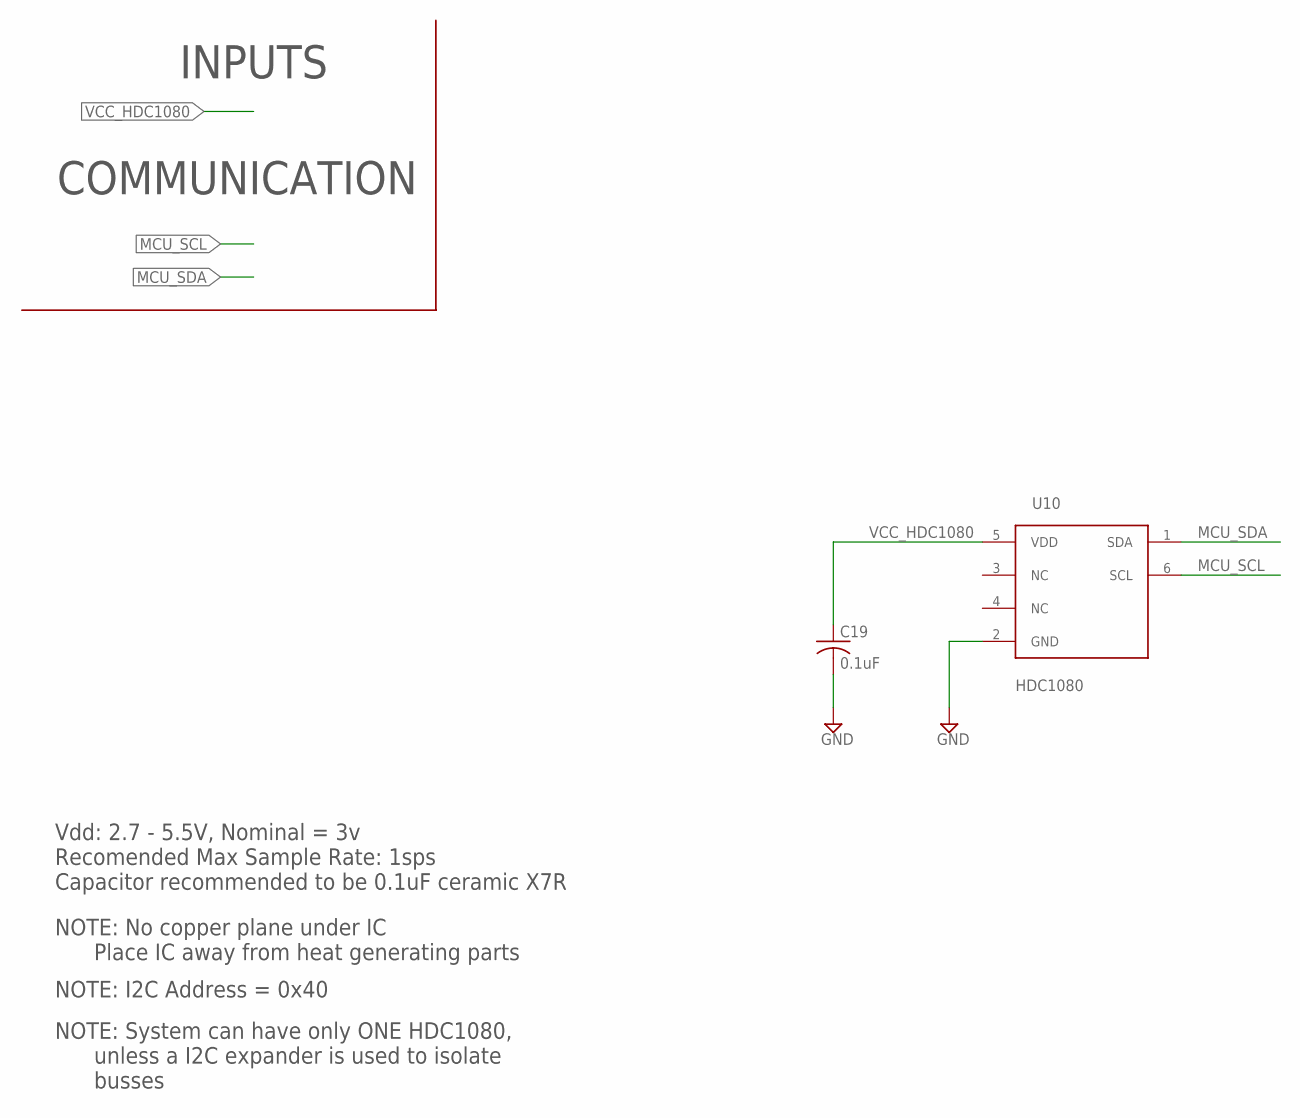
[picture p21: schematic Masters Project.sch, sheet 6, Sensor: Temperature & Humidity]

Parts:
C19: 0.1uF; C0603; PARTNO 08055C104KAT2A
U10: HDC1080; WSON-6; PARTNO HDC1080DMBT

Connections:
GND: C19.2, U10.2 (GND); also elsewhere on the board
MCU_SCL: U10.6 (SCL); also elsewhere on the board
MCU_SDA: U10.1 (SDA); also elsewhere on the board
VCC_HDC1080: C19.1, U10.5 (VDD); also elsewhere on the board

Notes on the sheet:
Vdd: 2.7 - 5.5V, Nominal = 3v Recomended Max Sample Rate: 1sps Capacitor recommended to be 0.1uF ceramic X7R
NOTE: No copper plane under IC Place IC away from heat generating parts
INPUTS
COMMUNICATION
NOTE: I2C Address = 0x40
NOTE: System can have only ONE HDC1080, unless a I2C expander is used to isolate busses

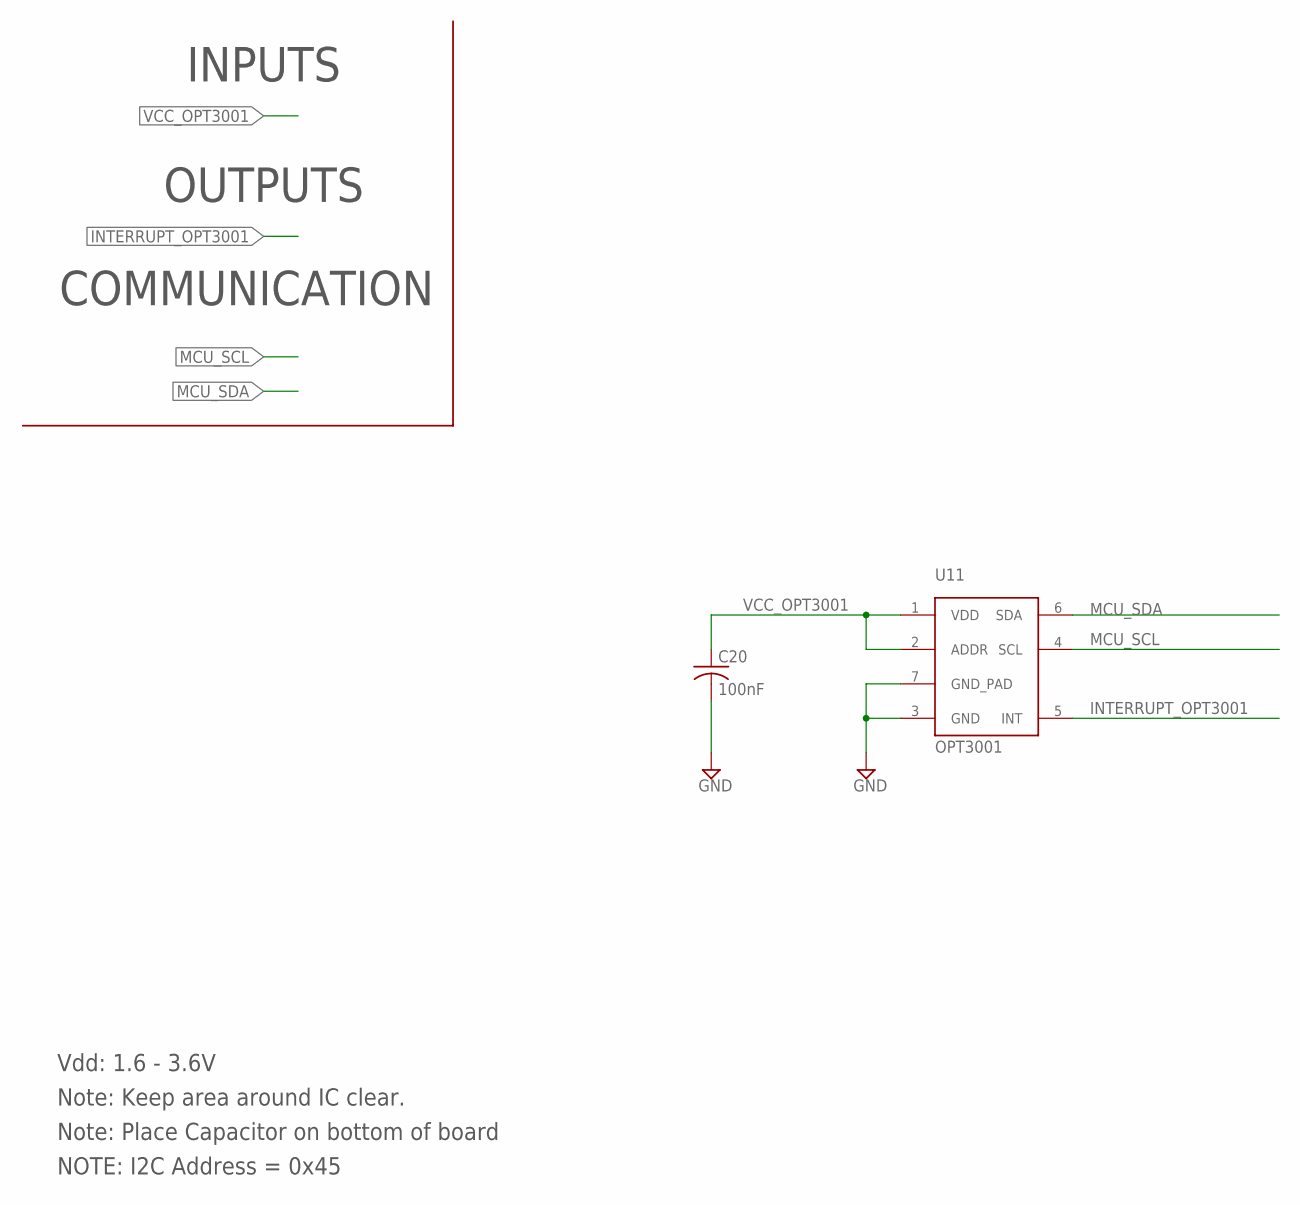
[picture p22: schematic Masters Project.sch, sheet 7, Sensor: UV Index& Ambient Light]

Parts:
C20: 100nF; C0603; PARTNO CC0603ZRY5V9BB104
U11: OPT3001; USON-6; PARTNO OPT3001DNPT

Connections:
GND: C20.2, U11.3 (GND), U11.7 (GND_PAD); also elsewhere on the board
INTERRUPT_OPT3001: U11.5 (INT); also elsewhere on the board
MCU_SCL: U11.4 (SCL); also elsewhere on the board
MCU_SDA: U11.6 (SDA); also elsewhere on the board
VCC_OPT3001: C20.1, U11.1 (VDD), U11.2 (ADDR); also elsewhere on the board

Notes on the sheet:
Vdd: 1.6 - 3.6V
Note: Keep area around IC clear.
INPUTS
COMMUNICATION
OUTPUTS
Note: Place Capacitor on bottom of board
NOTE: I2C Address = 0x45

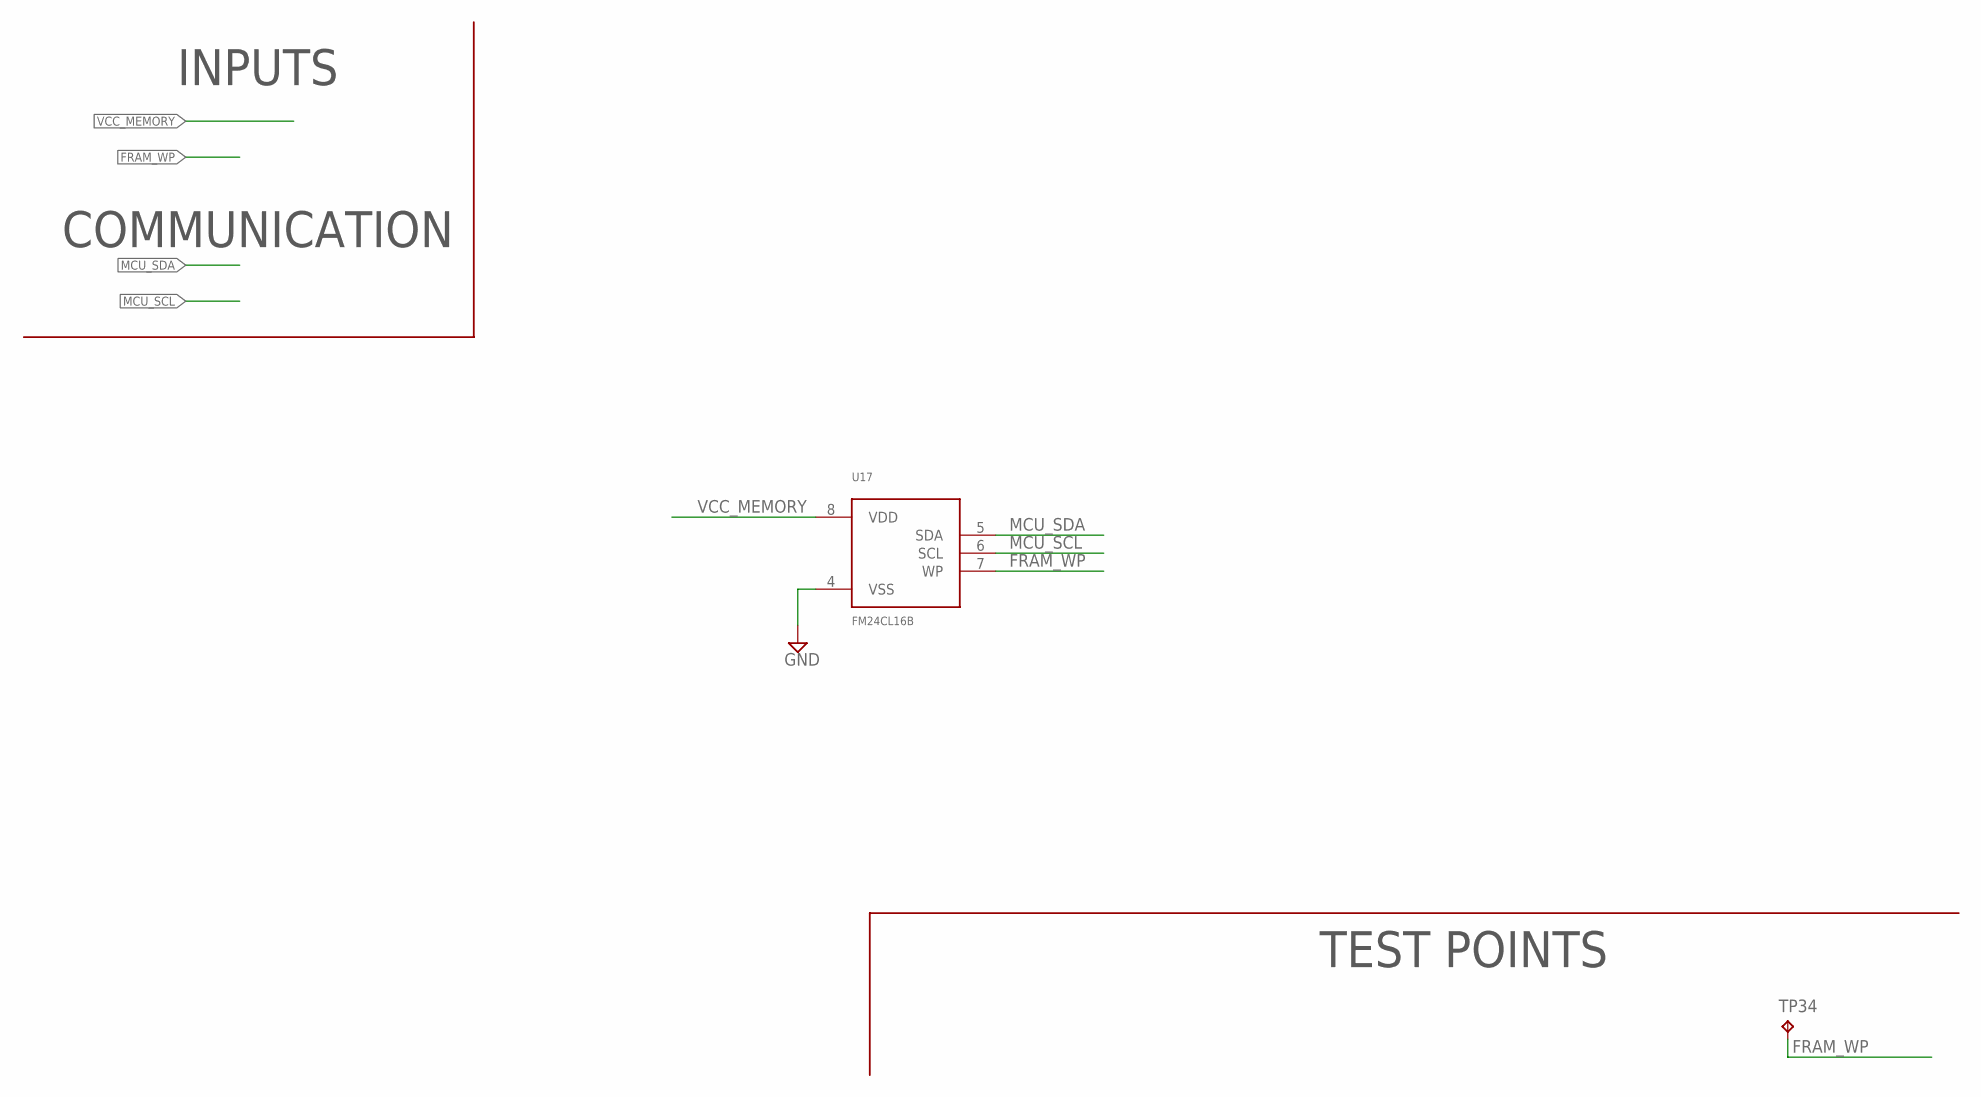
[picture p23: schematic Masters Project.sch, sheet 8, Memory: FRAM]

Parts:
TP34: TPB1,27; B1,27
U17: FM24CL16B

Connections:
FRAM_WP: TP34.TP, U17.7 (WP); also elsewhere on the board
GND: U17.4 (VSS); also elsewhere on the board
MCU_SCL: U17.6 (SCL); also elsewhere on the board
MCU_SDA: U17.5 (SDA); also elsewhere on the board
VCC_MEMORY: U17.8 (VDD); also elsewhere on the board

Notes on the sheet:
INPUTS
COMMUNICATION
TEST POINTS

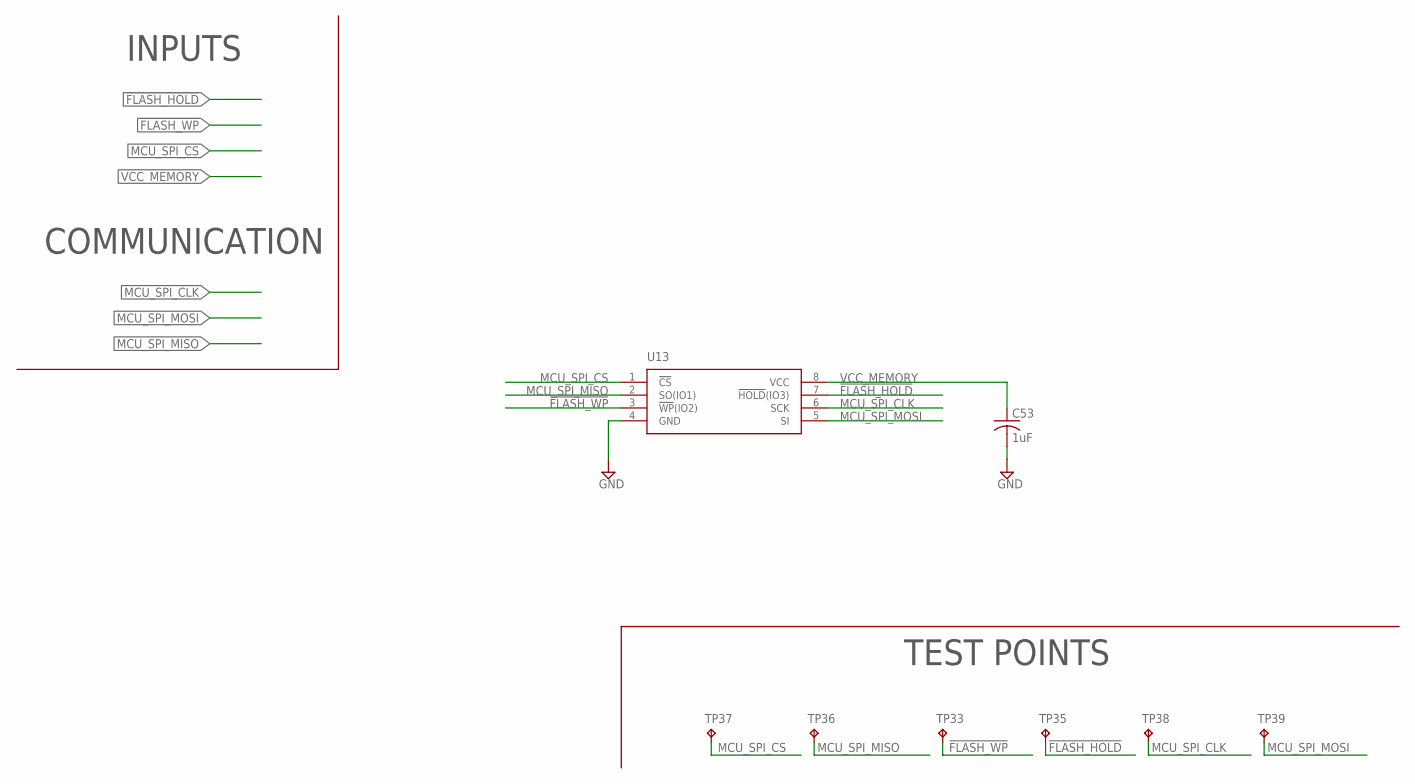
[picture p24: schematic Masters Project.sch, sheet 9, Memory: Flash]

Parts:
C53: 1uF; C0603; PARTNO C0805C220J5GACTU
TP33, TP35, TP36, TP37, TP38, TP39: TPB1,27; B1,27
U13: AT25SL128A; SON127P600X500X60-8N

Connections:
!FLASH_HOLD: TP35.TP, U13.7 (!HOLD!(IO3)); also elsewhere on the board
!FLASH_WP: TP33.TP, U13.3 (!WP!(IO2)); also elsewhere on the board
GND: C53.2, U13.4 (GND); also elsewhere on the board
MCU_SPI_CLK: TP38.TP, U13.6 (SCK); also elsewhere on the board
MCU_SPI_CS: TP37.TP, U13.1 (!CS); also elsewhere on the board
MCU_SPI_MISO: TP36.TP, U13.2 (SO(IO1)); also elsewhere on the board
MCU_SPI_MOSI: TP39.TP, U13.5 (SI); also elsewhere on the board
VCC_MEMORY: C53.1, U13.8 (VCC); also elsewhere on the board

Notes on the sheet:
TEST POINTS
INPUTS
COMMUNICATION

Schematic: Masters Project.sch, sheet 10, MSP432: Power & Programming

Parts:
C21: 1nF; C0603; PARTNO 08053F102K4T2A
C22, C23, C24, C25: 22pF; C0603; PARTNO C0805C220J5GACTU
C26, C29, C31, C33, C35: 100nF; C0603; PARTNO CC0603ZRY5V9BB104
C27: 4uF; C0603; PARTNO C0805C395K8PACTU
C28, C30, C32, C34: 4.7uF; C0603; PARTNO CL21A475KBQNNNE
JP12: CORTEX_DEBUG_10PIN; PARTNO 3220-10-0100-00
L1: 4.7uH; L-USL0805; PARTNO BRC2012T4R7MD
Q1: CPFBZ-A2C4-32.768KD6; PARTNO CPFBZ-A2C4-32.768KD6
Q2: ABM8-48.000MHZ-B2-T; CRYSTAL_4-SMD; PARTNO ABM8-48.000MHZ-B2-T
R18, R20: 1K; R0603; PARTNO RC0805JR-071KL
R26: 91k; R0603; PARTNO RC0805JR-0791KL
SW1: TACTILE-SWITCH-SMT; 7914G; PARTNO 7914G-1-000E
TP19, TP20, TP21: TPB1,27; B1,27
U12: MSP432P401R; LQFP100; PARTNO MSP432P401RIPZR

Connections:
!RST: C21.1, JP12.10 (NRESET), R20.2, SW1.1, SW1.2, TP19.TP, U12.83 (RSTN/NMI)
FREQ_HF: C24.1, Q2.P$1 (1), TP20.TP, U12.85 (PJ.2/HFXOUT)
FREQ_LF: C22.1, Q1.P$1 (1), TP21.TP, U12.41 (PJ.0/LFXIN)
GND: C21.2, C22.2, C23.2, C24.2, C25.2, C26.2, C27.2, C28.2, C29.2, C30.2, C31.2, C32.2, C33.2, C34.2, C35.2, JP12.3 (GND), JP12.5 (GND), JP12.9 (GNDDTCT), R26.1, SW1.3, SW1.4, U12.15 (DVSS1), U12.40 (AVSS3), U12.43 (AVSS1), U12.72 (DVSS2), U12.82 (DVSS3), U12.84 (AVSS2); also elsewhere on the board
unnamed: JP12.1 (VCC), R18.2
unnamed: R26.2, U12.44 (DCOR)
unnamed: L1.1, U12.14 (VSW)
unnamed: C26.1, C27.1, L1.2, U12.12 (VCORE)
unnamed: JP12.2 (SWDIO/TMS), U12.94 (SWDIO/TMS)
unnamed: JP12.6 (SWO/TDO), U12.93 (PJ.5/TDO/SWO)
unnamed: JP12.8 (NC/TDI), U12.92 (PJ.4/TDI/ADC14CLK)
unnamed: C23.1, Q1.P$4 (2), U12.42 (PJ.1/LFXOUT)
unnamed: JP12.4 (SWDCLK/TCK), U12.95 (SWCLK/TCK)
unnamed: C25.1, Q2.P$3 (2), U12.86 (PJ.3/HFXIN)
VCC_MCU: C28.1, C29.1, C30.1, C31.1, C32.1, C33.1, C34.1, C35.1, R18.1, R20.1, U12.13 (DVCC1), U12.45 (AVCC1), U12.73 (DVCC2), U12.87 (AVCC2); also elsewhere on the board

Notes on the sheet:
External JTAG/SWD To MCU & Low/Hogh Frequency Crystals
NOTE: 100nF decoupling capacitor should be a low-ESR ceramic
NOTE: L = LQM21PN4R7NGR
Reset Switch
Power
DVCC2
DVCC1
AVCC1
AVCC2
INPUTS
TEST POINTS
OUTPUTS
Decoupling
NOTE: Place as close to indicated pins as possible
NOTE: !RST line also uses internal R of MCU for filtering
NOTE: R18 Used for current limiting

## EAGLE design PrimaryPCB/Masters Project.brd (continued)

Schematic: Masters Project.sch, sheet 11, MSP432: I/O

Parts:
LED12: GREEN; CHIPLED_0603; PARTNO LG R971-KN-1
R24, R25: 10K; R0603; PARTNO RMCF0805JT10K0
R27: 1K; R0603; PARTNO RC0805JR-071KL
TP22, TP23, TP24, TP26, TP27, TP28, TP29, TP30: TPB1,27; B1,27
U12: MSP432P401R; LQFP100; PARTNO MSP432P401RIPZR

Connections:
!RTC_INT1: U12.22 (P2.6/PM_TA0.3); also elsewhere on the board
!RTC_INT2: U12.24 (P10.4/TA3.0/C0.7); also elsewhere on the board
CHARGE_STATUS: U12.32 (P3.0/PM_UCA2STE); also elsewhere on the board
DISPLAY_D/!C: TP27.TP, U12.36 (P3.4/PM_UCB2STE); also elsewhere on the board
FPGA_DONE: U12.23 (P2.7/PM_TA0.4); also elsewhere on the board
FRAM_WP: U12.4 (P1.0/UCA0STE); also elsewhere on the board
INTERRUPT_OPT3001: U12.5 (P1.1/UCA0CLK); also elsewhere on the board
MCU_EN_CTL3: U12.19 (P2.3/PM_UCA1TXD/PM_UCA1SIMO); also elsewhere on the board
MCU_EN_CTL4: U12.18 (P2.2/PM_UCA1RXD/PM_UCA1SOMI); also elsewhere on the board
MCU_EN_CTL5: U12.39 (P3.7/PM_UCB2SOMI/PM_UCB2SCL); also elsewhere on the board
MCU_EN_CTL6: U12.20 (P2.4/PM_TA0.1); also elsewhere on the board
MCU_FPGA_2: U12.71 (P5.7/TA2.2/VREF-/VEREF-/C1.6); also elsewhere on the board
MCU_FPGA_3: U12.70 (P5.6/TA2.1/VREF+/VEREF+/C1.7); also elsewhere on the board
MCU_FPGA_4: U12.69 (P5.5/A0); also elsewhere on the board
MCU_FPGA_5: U12.68 (P5.4/A1); also elsewhere on the board
MCU_FPGA_6: U12.67 (P5.3/A2); also elsewhere on the board
MCU_FPGA_7: U12.66 (P5.2/A3); also elsewhere on the board
MCU_FPGA_8: U12.65 (P5.1/A4); also elsewhere on the board
MCU_FPGA_9: U12.64 (P5.0/A5); also elsewhere on the board
MCU_FPGA_10: U12.63 (P4.7/A6); also elsewhere on the board
MCU_FPGA_11: U12.62 (P4.6/A7); also elsewhere on the board
MCU_FPGA_12: U12.61 (P4.5/A8); also elsewhere on the board
MCU_FPGA_13: U12.60 (P4.4/HSMCLK/SVMHOUT/A9); also elsewhere on the board
MCU_FPGA_14: U12.59 (P4.3/MCLK/RTCCLK/A10); also elsewhere on the board
MCU_FPGA_15: U12.58 (P4.2/ACLK/TA2CLK/A11); also elsewhere on the board
MCU_SCL: R25.1, TP29.TP, U12.11 (P1.7/UCB0SOMI/UCB0SCL); also elsewhere on the board
MCU_SDA: R24.1, TP30.TP, U12.10 (P1.6/UCB0SIMO/UCB0SDA); also elsewhere on the board
MCU_SD_HDC1080: U12.17 (P2.1/PM_UCA1CLK); also elsewhere on the board
MCU_SD_OPT3001: U12.16 (P2.0/PM_UCA1STE); also elsewhere on the board
unnamed: R27.2, U12.9 (P1.5/UCB0CLK)
unnamed: LED12.C, R27.1
P10.5: U12.25 (P10.5/TA3.1/C0.6); also elsewhere on the board
RTC_CLKOUT: U12.21 (P2.5/PM_TA0.2); also elsewhere on the board
SPI_CLK: TP24.TP, U12.33 (P3.1/PM_UCA2CLK); also elsewhere on the board
SPI_CS_DISPLAY: TP28.TP, U12.37 (P3.5/PM_UCB2CLK); also elsewhere on the board
SPI_CS_FPGA: U12.38 (P3.6/PM_UCB2SIMO/PM_UCB2SDA); also elsewhere on the board
SPI_MISO: U12.34 (P3.2/PM_UCA2RXD/PM_UCA2SOMI)
SPI_MOSI: TP26.TP, U12.35 (P3.3/PM_UCA2TXD/PM_UCA2SIMO); also elsewhere on the board
UART_RX_XBEE: TP23.TP, U12.6 (P1.2/UCA0RXD/UCA0SOMI); also elsewhere on the board
UART_TX_XBEE: TP22.TP, U12.7 (P1.3/UCA0TXD/UCA0SIMO); also elsewhere on the board
VCC_MCU: LED12.A, R24.2, R25.2; also elsewhere on the board

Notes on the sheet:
TEST POINTS
INPUTS
COMMUNICATION
OUTPUTS
I/O

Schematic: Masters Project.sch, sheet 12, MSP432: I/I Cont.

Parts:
JP3: 2X5_HEADER1.27MM; CORTEX_DEBUG_10PIN
TP31, TP32: TPB1,27; B1,27
U12: MSP432P401R; LQFP100; PARTNO MSP432P401RIPZR

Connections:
!FLASH_HOLD: U12.75 (P9.3/TA3.4); also elsewhere on the board
!FLASH_WP: U12.80 (P6.6/TA2.3/UCB3SIMO/UCB3SDA/C1.1); also elsewhere on the board
EINK_!RST: TP31.TP, U12.46 (P8.2/TA3.2/A23); also elsewhere on the board
EINK_BUSY: TP32.TP, U12.47 (P8.3/TA3CLK/A22); also elsewhere on the board
GND: JP3.2, JP3.4; also elsewhere on the board
MCU_FPGA_1: U12.74 (P9.2/TA3.3); also elsewhere on the board
MCU_SPI_CLK: U12.77 (P6.3/UCB1CLK/C1.4); also elsewhere on the board
MCU_SPI_CS: U12.76 (P6.2/UCB1STE/C1.5); also elsewhere on the board
MCU_SPI_MISO: U12.79 (P6.5/UCB1SOMI/UCB1SCL/C1.2); also elsewhere on the board
MCU_SPI_MOSI: U12.78 (P6.4/UCB1SIMO/UCB1SDA/C1.3); also elsewhere on the board
P7.5: JP3.9, U12.27 (P7.5/PM_TA1.3/C0.4)
P7.6: JP3.7, U12.28 (P7.6/PM_TA1.2/C0.3)
P7.7: JP3.5, U12.29 (P7.7/PM_TA1.1/C0.2)
P8.0: JP3.3, U12.30 (P8.0/UCB3STE/TA1.0/C0.1)
P8.1: JP3.1, U12.31 (P8.1/UCB3CLK/TA2.0/C0.0)
P10.5: JP3.6; also elsewhere on the board
VCC_MCU: JP3.8, JP3.10; also elsewhere on the board
XBEE_RESET: U12.26 (P7.4/PM_TA1.4/C0.5); also elsewhere on the board

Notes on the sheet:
External Pin Connections
TEST POINTS
INPUTS
OUTPUTS
I/O
COMMUNICATION

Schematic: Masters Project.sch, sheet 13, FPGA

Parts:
C37, C38, C42, C43, C46, C47, C50, C51, C54, C55: 0.1uF; C0603; PARTNO 08055C104KAT2A
JP1, JP4: 2X5_HEADER1.27MM; CORTEX_DEBUG_10PIN
R30, R31, R32: 5k; R0603; PARTNO RC0805FR-075K1L
R35: 2k; R0603; PARTNO RC0805FR-072KL
U1: LCMXO2-640HC-4TG100C-NEW; QFP50P1600X1600X160-100N

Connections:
FPGA_DONE: U1.76 (PT11D/DONE); also elsewhere on the board
GND: C37.2, C38.2, C42.2, C43.2, C46.2, C47.2, C50.2, C51.2, C54.2, C55.2, JP1.10, JP4.8, R35.1, U1.6 (GND), U1.22 (GND), U1.33 (GND), U1.44 (GND), U1.56 (GND), U1.72 (GND), U1.79 (GND), U1.92 (GND); also elsewhere on the board
MCU_FPGA_1: U1.28 (PB4B); also elsewhere on the board
MCU_FPGA_2: U1.29 (PB4C); also elsewhere on the board
MCU_FPGA_3: U1.30 (PB4D); also elsewhere on the board
MCU_FPGA_4: U1.31 (PB6A/MCLK/CCLK); also elsewhere on the board
MCU_FPGA_5: U1.32 (PB6B/SO/SPISO); also elsewhere on the board
MCU_FPGA_6: U1.34 (PB6C/PCLKT2_0); also elsewhere on the board
MCU_FPGA_7: U1.35 (PB6D/PCLKC2_0); also elsewhere on the board
MCU_FPGA_8: U1.36 (PB10A); also elsewhere on the board
MCU_FPGA_9: U1.37 (PB10B); also elsewhere on the board
MCU_FPGA_10: U1.38 (PB10C/PCLKT2_1); also elsewhere on the board
MCU_FPGA_11: U1.39 (PB10D/PCLKC2_1); also elsewhere on the board
MCU_FPGA_12: U1.40 (PB12A); also elsewhere on the board
MCU_FPGA_13: U1.41 (PB12B); also elsewhere on the board
MCU_FPGA_14: U1.42 (PB12C); also elsewhere on the board
MCU_FPGA_15: U1.43 (PB12D); also elsewhere on the board
PT9A: JP1.8, U1.88 (PT9A/PCLKT0_1)
PT9B: JP1.6, U1.87 (PT9B/PCLKC0_1)
PT9C: JP1.4, U1.86 (PT9C/SCL/PCLKT0_0)
PT9D: JP1.2, U1.85 (PT9D/SDA/PCLKC0_0)
PT10A: JP1.3, U1.84 (PT10A)
PT10B: JP1.5, U1.83 (PT10B)
PT10C: JP1.7, U1.82 (PT10C/JTAGENB)
PT10D: JP1.9, U1.81 (PT10D/PROGRAMN)
SPI_CS_FPGA: U1.48 (PB14C/SN); also elsewhere on the board
TCK: JP4.6, R35.2, U1.91 (PT7C/TCK)
TDI: JP4.5, R31.1, U1.94 (PT7B/TDI)
TDO: JP4.7, R30.1, U1.95 (PT7A/TDO)
TMS: JP4.3, R32.1, U1.90 (PT7D/TMS)
VCC_FPGA: C37.1, C38.1, C42.1, C43.1, C46.1, C47.1, C50.1, C51.1, C54.1, C55.1, JP1.1, JP4.1, R30.2, R31.2, R32.2, U1.5 (VCCIO3), U1.23 (VCCIO3), U1.26 (VCCIO2), U1.46 (VCCIO2), U1.50 (VCC), U1.55 (VCCIO1), U1.73 (VCCIO1), U1.80 (VCCIO0), U1.93 (VCCIO0), U1.100 (VCC); also elsewhere on the board

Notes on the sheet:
Decoupling capacitors
JTAG Programmer
POWER
MCU-FPGA Connections
VCCIO1
VCCIO2
VCCIO3
VCCIO0
INPUTS
OUTPUTS
COMMUNICATION
I/O Connections
External Header
NOTE: Place close to indicated voltage pins.
UNUSED

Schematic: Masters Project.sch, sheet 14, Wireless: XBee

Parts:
C57: 47uF; C0603; PARTNO GRM21BR61A476ME15L
JP2: 1X3_HEADER; 1X3_FEMALE_HEADER_THROUGH_HOLE; PARTNO PRPC040SAAN-RC
JP26: XBEE-1B1; XBEE-1; PARTNO NPPN101BFCN-RC
LED14, LED15, LED18: GREEN; CHIPLED_0603; PARTNO LG R971-KN-1
LED16, LED17: GREEN; SML0805; PARTNO LG R971-KN-1
R37, R38, R39, R40, R41: 1K; R0603; PARTNO RC0805JR-071KL

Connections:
ASSOCIATE_LED: JP26.15 (DIO5), R39.1
GND: C57.2, JP26.10 (GND), LED16.C, LED17.C, LED18.C; also elsewhere on the board
unnamed: LED15.C, R38.2
unnamed: LED14.C, R37.2
unnamed: LED16.A, R39.2
unnamed: LED18.A, R41.2
unnamed: LED17.A, R40.2
RSSI: JP26.6 (RSSI), R41.1
STATUS_LED: JP26.13 (DIO9), R40.1
UART_RX_XBEE: JP26.2 (DOUT), R37.1; also elsewhere on the board
UART_TX_XBEE: JP26.3 (DIN), R38.1; also elsewhere on the board
VCC_XBEE: C57.1, JP26.1 (VDD), LED14.A, LED15.A; also elsewhere on the board
XBEE_CTS: JP2.2, JP26.12 (CTS)
XBEE_DTR: JP2.3, JP26.9 (DTR)
XBEE_RESET: JP26.5 (RESET); also elsewhere on the board
XBEE_RTS: JP2.1, JP26.16 (RTS)

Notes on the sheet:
NOTE: This module can be swapped for any module that is pn compattble with Xbee. For example the WiFi or RF modules by digi can be placed here.
NOTE: Minimum connections: VCC, GND, DOUT & DIN
NOTE: Do not populate for reduced current
Decoupling Capacitors
Status LED's
XBee
NOTE: Populate J2 only if XBee upgrades are needed
XBee Update
NOTE: Use to update software on XBee SOC
NOTE: Minimum connections for updating firmware: VCC, GND, DIN, DOUT, RTS & DTR
INPUTS
COMMUNICATION

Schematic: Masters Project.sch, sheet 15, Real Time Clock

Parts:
C68: 11mF; C1210K
Q9: ABS07-LR; 2-SMD
R3: 1K; R0603
TP40, TP41, TP42: TPB1,27; B1,27
U16: PCF8523; TSSOP14

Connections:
!RTC_INT1: TP40.TP, U16.13 (!INT1); also elsewhere on the board
!RTC_INT2: TP42.TP, U16.7 (!INT2); also elsewhere on the board
+BAT: R3.2, U16.4 (VBAT), U16.14 (VDD); also elsewhere on the board
GND: C68.2, U16.5 (VSS); also elsewhere on the board
MCU_SCL: U16.11 (SCL); also elsewhere on the board
MCU_SDA: U16.10 (SDA); also elsewhere on the board
unnamed: Q9.2, U16.1 (OSCI)
unnamed: Q9.1, U16.2 (OSCO)
RTC_CLKOUT: TP41.TP, U16.8 (CLKOUT); also elsewhere on the board
RTC_VCAP: C68.1, R3.1

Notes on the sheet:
SuperCap
NOTE: Resistor used to provide current limiting to the capacitor. Larger resistor = longer RC time constant = longer time to charge
Real Time Clock
NOTE: At ambiant temperature the average supply is 150nA. The maximum supply current is 3.6uA.
TEST POINTS
INPUTS
COMMUNICATION
OUTPUTS

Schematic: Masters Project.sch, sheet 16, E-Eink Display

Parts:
C1, C2, C36, C39, C40, C41, C44, C45, C48, C49, C52: 1uF; C0603
D1, D3, D4: SCHOTTKY; SOD3716X128
L2: 100uH; LPS3015
Q3: MOSFET-NCH; SOT95P237X112-3
R1: 0.47; R0603
R2: 100k; R0603
U18: 4.2-E-INK-DISPLAY; FPC-24PIN-0.5MM

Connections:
DISPLAY_D/!C: U18.11 (D/!C); also elsewhere on the board
EINK_!RST: U18.10 (!RST); also elsewhere on the board
EINK_BUSY: U18.9 (BUSY); also elsewhere on the board
GDR: Q3.1 (G), R2.2, U18.2 (GDR)
GND: C1.2, C2.2, C36.2, C39.2, C40.2, C41.2, C44.2, C45.2, C48.2, C49.2, D4.2 (C), R1.1, R2.1, U18.8 (BS1), U18.17 (VSS); also elsewhere on the board
PREVGH: C48.1, D1.2 (C), U18.21 (PREVGH)
PREVGL: C49.1, D3.1 (A), U18.23 (PREVGL)
RESE: Q3.2 (S), R1.2, U18.3 (RESE)
SPI_CLK: U18.13 (D0(SCK)); also elsewhere on the board
SPI_CS_DISPLAY: U18.12 (!CS); also elsewhere on the board
SPI_MOSI: U18.14 (D1(MOSI)); also elsewhere on the board
SW: C52.1, D1.1 (A), L2.1, Q3.3 (D)
SWGL: C52.2, D3.2 (C), D4.1 (A)
VCC_DISPLAY: C41.1, L2.2, U18.15 (VDDIO), U18.16 (VCI); also elsewhere on the board
VCOM: C40.1, U18.24 (VCOM)
VDD: C1.1, U18.18 (VDD)
VGH: C45.1, U18.5 (VGH)
VGL: C44.1, U18.4 (VGL)
VPP: C2.1, U18.19 (VPP)
VSH: C36.1, U18.20 (VSH)
VSL: C39.1, U18.22 (VSL)

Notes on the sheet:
RATED >= 25V
RATED>= 50V
RATED >=50V
Power Converter
INPUTS
COMMUNICATION
OUTPUTS

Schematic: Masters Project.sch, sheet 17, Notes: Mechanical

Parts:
FD1, FD2, FD3, FD4, FD5, FD6, FD7, FD8: FIDUCIAL1X2; FIDUCIAL-1X2
H1, H2, H3, H4: STAND-OFF

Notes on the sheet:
Fiducial One per corner, top and bottom
Mounting Hole One per corner
BOTTOM
TOP
GND
Stackup

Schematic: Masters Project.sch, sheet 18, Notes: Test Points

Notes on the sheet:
TP1: +BAT TP2: GND TP3: VCC_USB TP4: VCC_HDC1080 TP5: VCC_OPT3001 TP6: VCC_FPGA TP7: VCC_XBEE TP8: VCC_MEMORY TP9: VCC_DISPLAY TP10: VCC_MCU TP11: GND TP12: GND TP13: GND TP14: GND TP15: GND TP16: GND TP17: GND TP18: GND TP19: !RST TP20: N$139
TP21: N$131 TP22: UART_TX_XBEE TP23: UART_RX_XBEE TP24: SPI_CLK TP25: CHARGE_STATUS TP26: SPI_MOSI TP27: DISPLAY_D/!C TP28: SPI_CS_DISPLAY TP29: MCU_SCL TP30: MCU_SDA TP31: EINK_!RST TP32: EINK_BUSY TP33: !FLASH_WP TP34: FRAM_WP TP35: !FLASH_HOLD TP36: MCU_SPI_MISO TP37: MCU_SPI_CS TP38: MCU_SPI_CL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

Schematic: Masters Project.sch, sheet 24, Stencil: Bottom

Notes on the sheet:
N/A



Board: 2 copper layers, 82.0 x 77.3 mm, 194 parts (47 on the bottom side), 127 nets.

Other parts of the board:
U$1: UC_DAVIS_EE_1.00_INCH
U$2: UC_DAVIS_ENG
U$3: MCSG_SMALL

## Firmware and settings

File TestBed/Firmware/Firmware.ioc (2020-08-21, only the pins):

Mcu.UserName=STM32G431C6Tx
PB11.Signal=USART3_RX
PB13.Signal=SPI2_SCK
PB15.Signal=SPI2_MOSI
PA12.Signal=USB_DP
PB6.Signal=GPIO_Input
PB7.Signal=I2C1_SDA
PA8.Signal=S_TIM1_CH1
PA0.Signal=ADC1_IN1
PB1.Signal=GPIO_Input
PA6.Signal=ADC2_IN3
PA10.Signal=S_TIM1_CH3
PA15.Signal=USART2_RX
PA3.Signal=ADC1_IN4
PA13.Signal=SYS_JTMS-SWDIO
PA9.Signal=S_TIM1_CH2
PA1.Signal=ADC1_IN2
PB10.Signal=USART3_TX
PB14.Signal=SPI2_MISO
PA5.Signal=ADC2_IN13
PB8-BOOT0.Signal=I2C1_SCL
PA2.Signal=ADC1_IN3
PB3.Signal=USART2_TX
PA4.Signal=ADC2_IN17
PA11.Signal=USB_DM
PA14.Signal=SYS_JTCK-SWCLK
PB0.Signal=ADC1_IN15
PB12.Signal=GPIO_Output
PA7.Signal=ADC2_IN4

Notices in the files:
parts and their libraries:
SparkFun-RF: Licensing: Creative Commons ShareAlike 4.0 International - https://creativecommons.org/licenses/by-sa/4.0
